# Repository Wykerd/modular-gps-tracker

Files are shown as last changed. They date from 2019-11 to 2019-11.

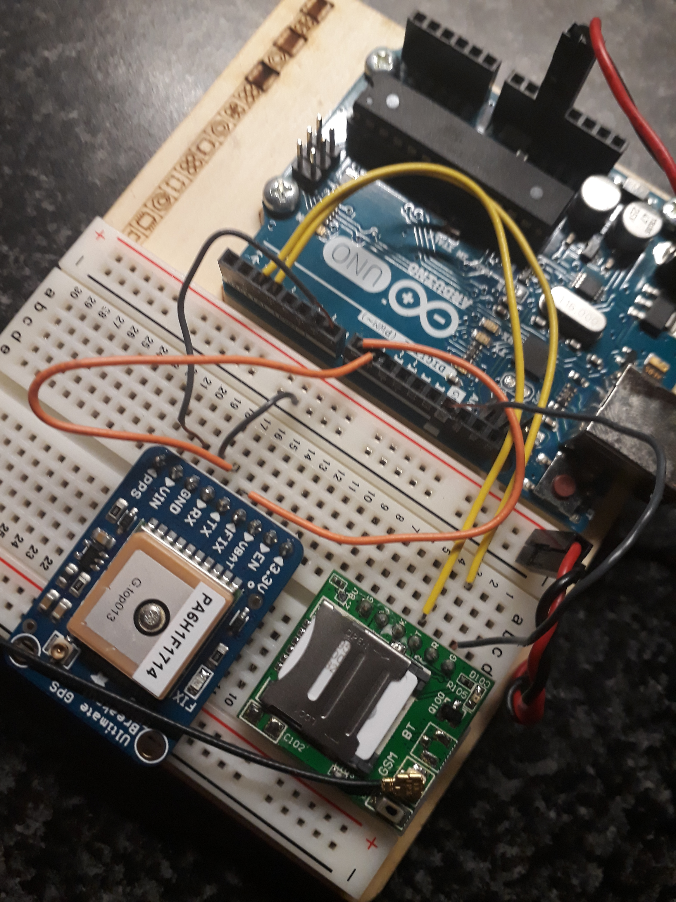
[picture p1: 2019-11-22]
Images/Hardware/20180210_222112.jpg

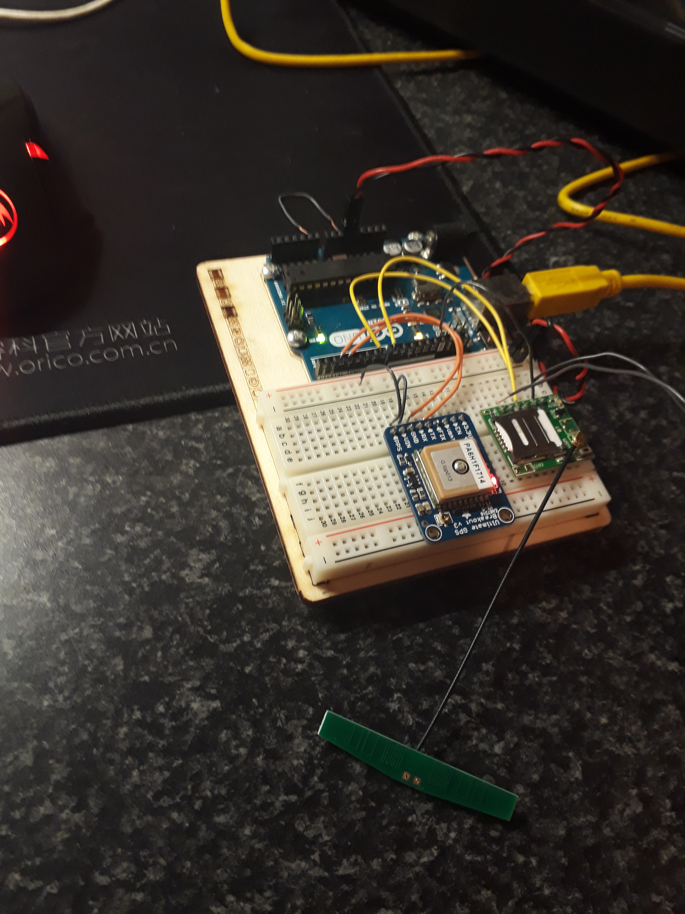
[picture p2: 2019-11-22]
Images/Hardware/20180122_201226.jpg

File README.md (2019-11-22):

# Modular GPS Tracker

This is a project made by me in 2018 when I was 16.

This project entered into the Eskom Expo Sciencefair.

Excuse the messy file structures and odd files. I had no idea of git at the time of making the project and this was a big learning experience for me.

The project is fully documented in ``Report File.docx`` Word document. An pdf converted version (which may be outdated) can be found as ``Report File*.pdf``

I might return to this project in the future but using a diffirent repo. If so, I will archive this project.

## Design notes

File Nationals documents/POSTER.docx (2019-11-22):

INTRODUCTION

Governmental Statistics show that there are high levels of theft in South Africa. Therefore, there is a need for a way to retrieve stolen goods like vehicles as well as personal property.

Although there are already GPS Tracking devices on the market, most of them are expensive and can only be used for one purpose.

ENGINEERING GOAL

The goal of this project is to design and manufacture a modular GPS tracking device that can accurately track stolen objects from anywhere in the country. The device will be modular allowing the user to add additional functionality to the core tracking module. The device should be mass producible and use pre-existing communication infrastructure to locate the device. There should be no third party involved in locating the device.

In addition to this, a secondary datalogging module will also be created to demonstrate the modularity of the core GPS Tracking device. This module should store location data like routes travelled on an SD Card in a common file format

PROCEDURES FOR CORE MODULE

First, the components that were required to design the core device was chosen. The three main components used in the device is a microcontroller that interfaces with and controls all the chips, a GPS module, and GSM module (used to send and receive SMSs)

The schematic and PCB layout was designed in a free CAD software called EasyEDA. The PCB layout was sent to a factory to be fabricated.

After the components were purchased and the PCBs arrived from the factory, the board was assembled.

Software had to be made for the microcontroller so that the device would function properly. The software was created in the Arduino IDE and was programmed in C.

Two cases were designed and printed to house the PCB and make the device more modular. It is designed to make it easier for the other modules to attach to the core module.

Lastly, the device was tested against the design criteria to determine how well it performed.

PROCEDURES FOR DATALOGGING MODULE

As with the core module, the components required had to be chosen first. The main components used in the datalogger is a microcontroller that controls writing to the SD Card, an USB-to-TTL UART Converter that makes it possible to update the software of the core module via the onboard USB port. The power from the USB port is used by the charge management IC to charge a 18650 Lithium-Ion battery.

The schematic and PCB layouts were created next and the PCB layout was sent to a factory to be fabricated.

After the components and PCBs arrived from the factory, the boards were assembled.

A New version of software had to be written for the core module for it to be able to communicate with the microcontroller of the datalogger, which code was also written for so that it can communicate and write data to the SD Card.

Lastly, the secondary datalogging module was tested with the core module against the design criteria to determine how well it performed.

RESULTS

P R O D U C T I O N

Both the core and secondary datalogging devices are contained on single multi-layered PCBs thus these devices can easily be manufactured as PCB fabrication is a very fast and cheap process.

Neither the core or datalogging module uses off the shelf components resulting in a steep drop in the price per unit.

All the components on both the core and datalogger are surface mount components, these types of components are the most common type components used in factories, it can easily be assembled by pick and place machines minimizing the need for human involvement in production (which further decreases production cost).

C O R E M O D U L E

The core device uses SMS to communicate with the user. Thus, it does not require a subscription to a third party.

The core device is modular. The code of the device can be changed and there are 3 programmable pins available for use by other modules added later.

RESULTS

D A T A L O G G I N G M O D U L E

The secondary datalogging module is capable of logging location data in a common file format called GPX. It is the standard format for logging location data and can be used by fitness apps and software map apps.

The device is lightweight weighing only 22 grams without the battery and 68 grams with the battery.

C O M P A R I S O N T O E X I S T I N G T R A C K E R S

Criterion | Common GPS Tracker | Modular GPS GSM Tracker
Upgradability | Most GPS trackers on the market have a closed ecosystem and are closed source. Software cannot be upgraded and there is no way to add additional hardware to the device. It is impossible to add additional functionality to these trackers | This tracker’s software is open source and can easily be upgraded via a computer. The tracker’s hardware has 3 I/O pins that can be programmed. Third-party developers can create their own hardware and software that adds additional functions to the device
Applications | Can be used to track a lot of items including people and vehicles, but other uses are limited. | Can be used to track a lot of items but can also be used for other applications like detecting odd movement of farm animals, notifying the user when the tracker exits a certain region etc.

APPLICATIONS

Since the core device is modular, it can be used for a variety of applications.

It can be used as a standalone in a vehicle, put inside a wallet or bag or it can be given to a child to monitor his/her whereabouts.

The device works the best outdoors, which narrows the uses of the device if a highly accurate location is required.

The core device can be used with the datalogging module by shipping companies to track the route that a shipment followed. It can be used by truck companies to track where their drivers drove during their shifts, or simply to record/log a workout or vehicle trip.

POSSIBLE EXTENSIONS

Improvements can be made to extend the device’s battery life.

More software can be created to make the user experience better or allow for additional functionality without more hardware and even more modules could be created to add functionality.

The GSM antenna can be put onto the PCB making the assembly process easier.

DISCUSSION

Each prototype of both modules got smaller because as prototypes were developed, the components used for testing the device became unnecessary and were removed leading to a smaller form factor. This also lead to a decrease in current draw.

The core device has several limitations: The device can only get a GPS fix if it is outside unless it is placed near a window. The device will function indoors if an initial GPS fix was gained outside.

The limitations of the datalogging module is that it can only write data to the SD Card, the core module cannot read any data from the SD Card. This issue can be minimized by rewriting the code of the MCU of the datalogger to allow reading from the SD Card as well.

CONCLUSION

According to all the results obtained in this project, the Modular SMS GPS Module designed and manufactured meets the requirements and criteria needed to accomplish the engineering goal. It is modular, uses a low current, is cheap to manufacture and requires no subscription to a third-party company.

The datalogging module designed and manufactured also meets the requirements needed to accomplish the engineering goal. It logs to an SD Card in a common file format and works seamlessly with the core module.

Therefore, in conclusion, the project has achieved its goal.

ACKNOWLEDGEMENTS

- Thanks Rochelle and Malan Wykerd for funding the research of core module and everyone who sponsored money for the datalogging module’s research.
- Thanks Johann Erasmus for soldering the first attempt at assembling the final prototype, helping with the debugging of the final prototype of the core module’s first attempt, and soldering one of the datalogging modules.
- Thanks Dr. Danie Ludick (PhD) for organizing with the University of Stellenbosch to populate the final prototype of the core module and datalogging module, reading through my designs and helping to debug the first attempt to assemble the final prototype of the core.
- Thanks to Grant Parkes for giving advice regarding the case design and for arranging the manufacturing of the case.
- Unpopulated PCBs fabricated by JLCPCB.
- ALL IMAGES ON THIS POSTER IS TAKEN BY DANIEL WYKERD
- Poster background watermark retrieved from https://openclipart.org/detail/296685/seamless-circuit-board-pattern

BIBLIOGRAPHY

1. Arduino, n.d.. ArduinoToBreadboard. [Online] Available at: https://www.arduino.cc/en/Tutorial/ArduinoToBreadboard [Accessed 13 04 2018].
2. Arduino, n.d.. Reference GSM Library. [Online] Available at: https://www.arduino.cc/en/Reference/GSM [Accessed 06 02 2018].
3. SIMCom Wireless Solutions, 2017. SIM800C Hardware Design. [Online] Available at: http://simcom.ee/documents/SIM800C/SIM800C_Hardware_Design_V1.05.pdf [Accessed 8 5 2018].
4. Adafruit Industries, 2012. Learn Adafruit Ultimate GPS Downloads. [Online] Available at: https://learn.adafruit.com/adafruit-ultimate-gps/downloads [Accessed 5 5 2018].

FULL BIBLIOGRAPHY IN REPORT FILE

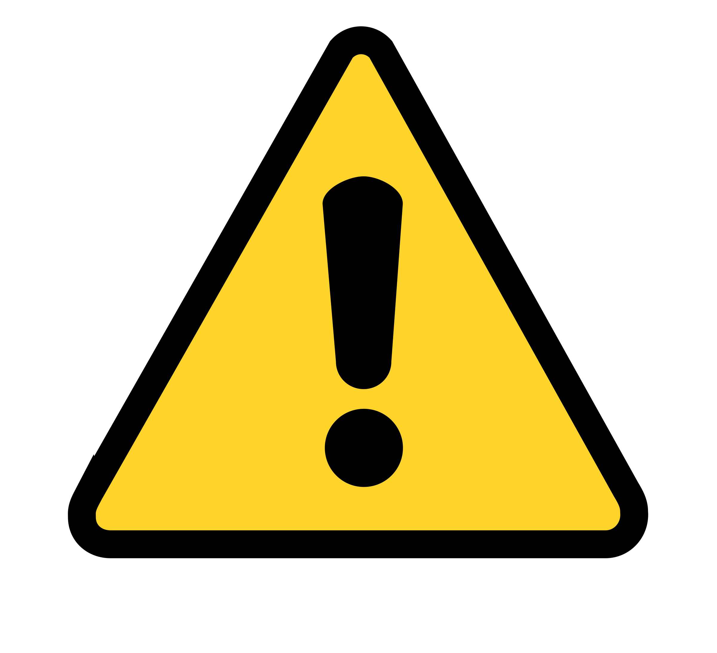
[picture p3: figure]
Image result for warning transparent
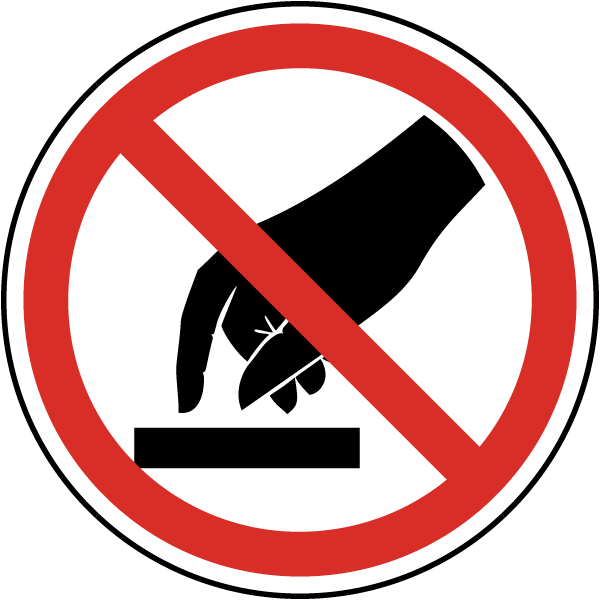
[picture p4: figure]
Image result for do not touch

DO NOT TOUCH THE ELECTRONICS!

THE ELECTRONICS ARE ELECTROSTATIC SENSITIVE

MODULAR

GPS GSM

TRACKER

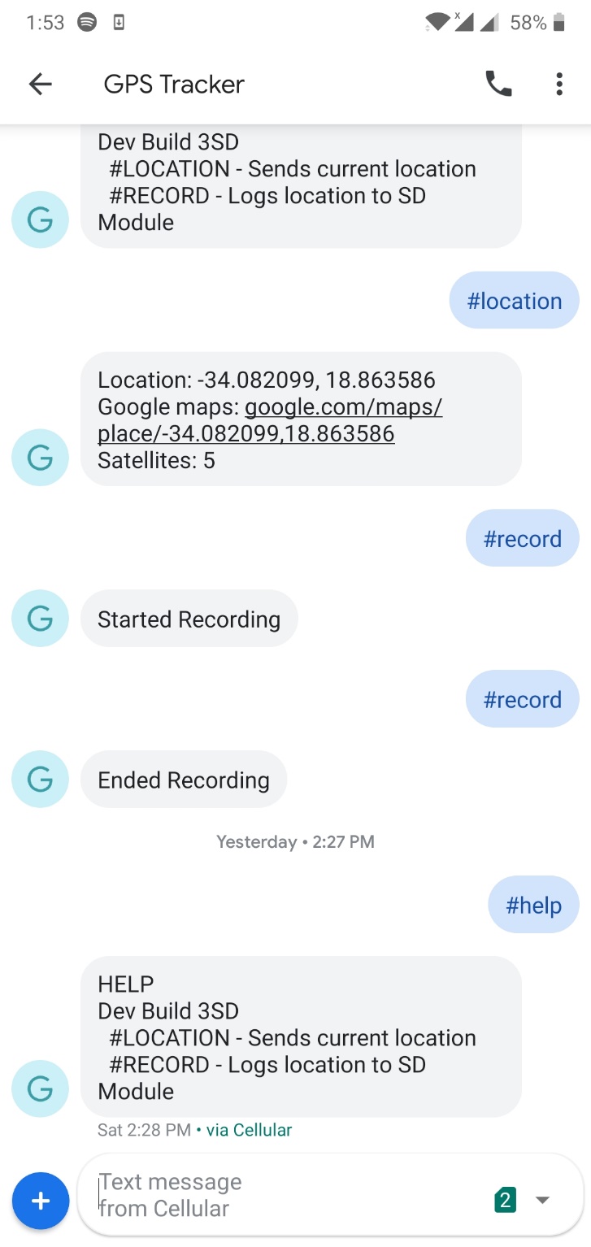
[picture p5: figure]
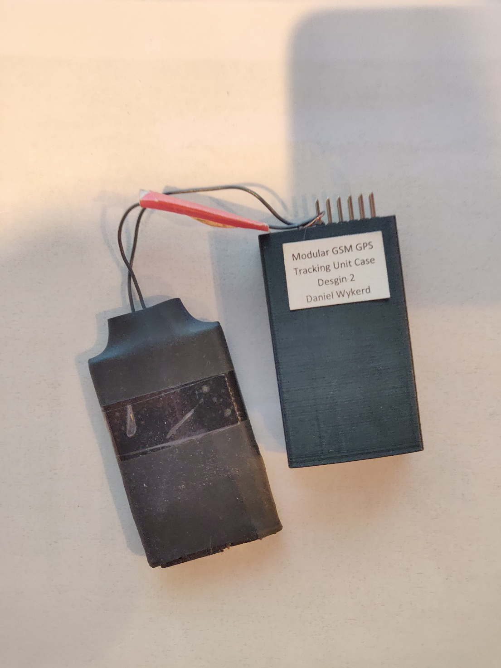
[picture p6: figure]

STANDALONE CORE MODULE SETUP

DANIEL

WYKERD

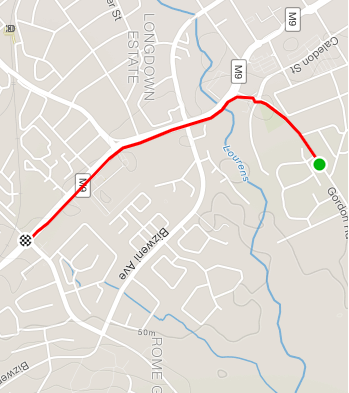
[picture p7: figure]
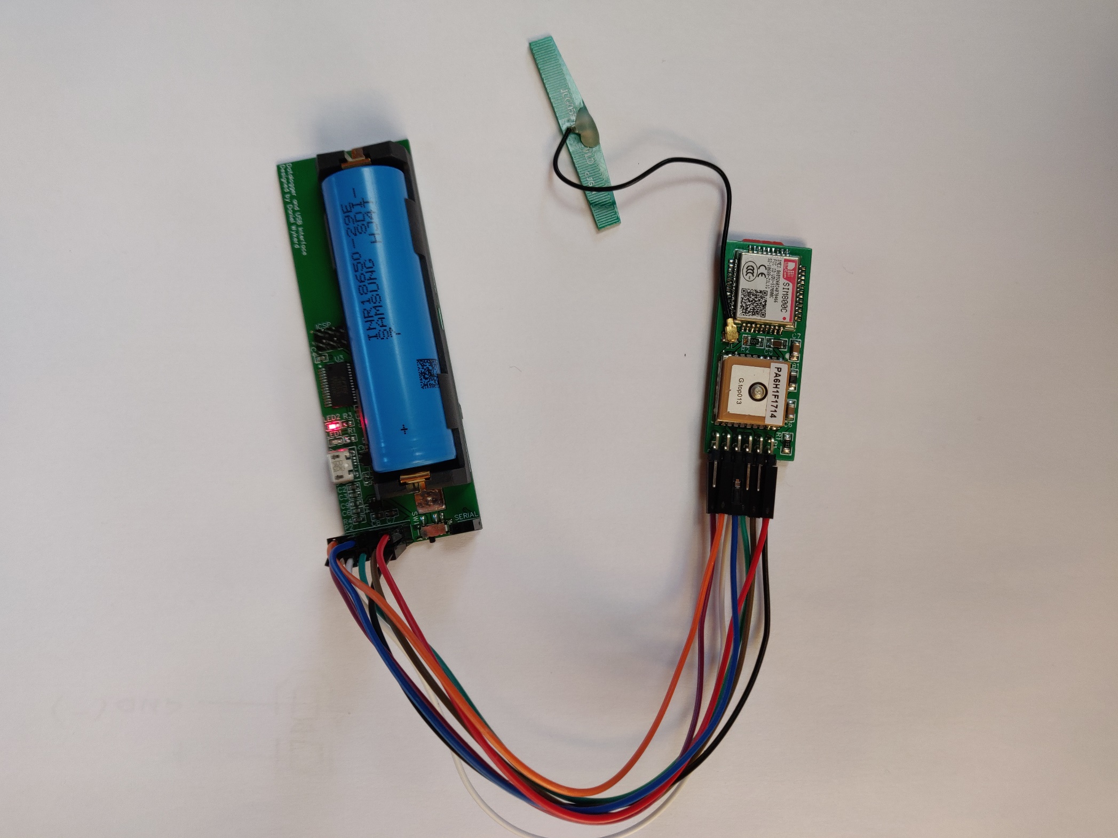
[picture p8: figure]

DATALOGGING MODULE SETUP

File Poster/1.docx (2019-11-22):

MODULAR

GSM GPS

TRACKER

INTRODUCTION

Governmental Statistics show that there are high levels of theft in South Africa. Therefore, there is a need for a way to retrieve stolen goods like vehicles as well as personal property.

Although there are already GPS Tracking devices on the market, most of them are expensive and can only be used for one purpose.

ENGINEERING GOAL

The goal of this project is to design and manufacture a modular GPS tracking device that can accurately track stolen objects from anywhere in the country. The device will be modular allowing the user to add additional functionality to the core tracking module. The device should be mass producible and use pre-existing communication infrastructure to locate the device. There should be no third party involved in locating the device.

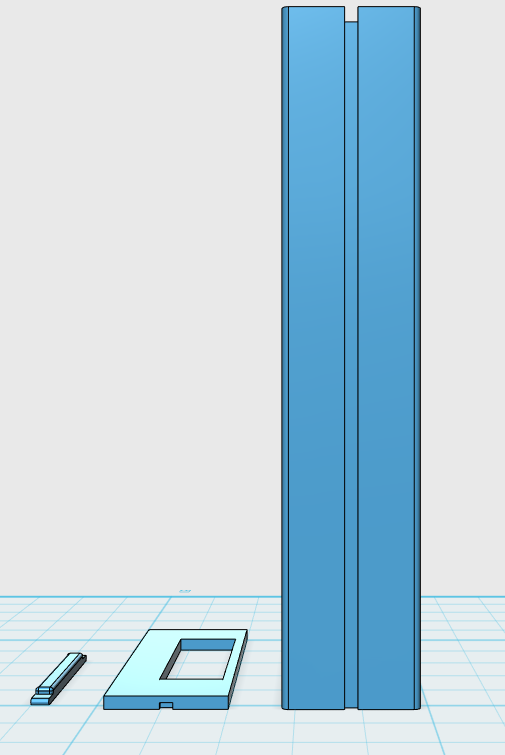
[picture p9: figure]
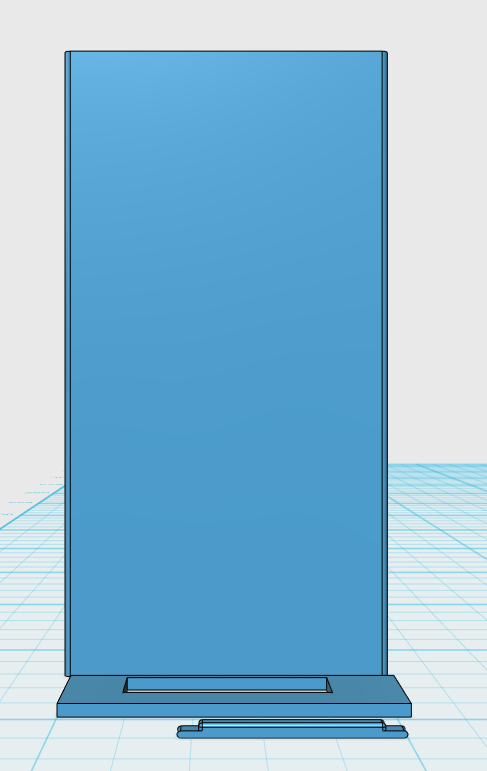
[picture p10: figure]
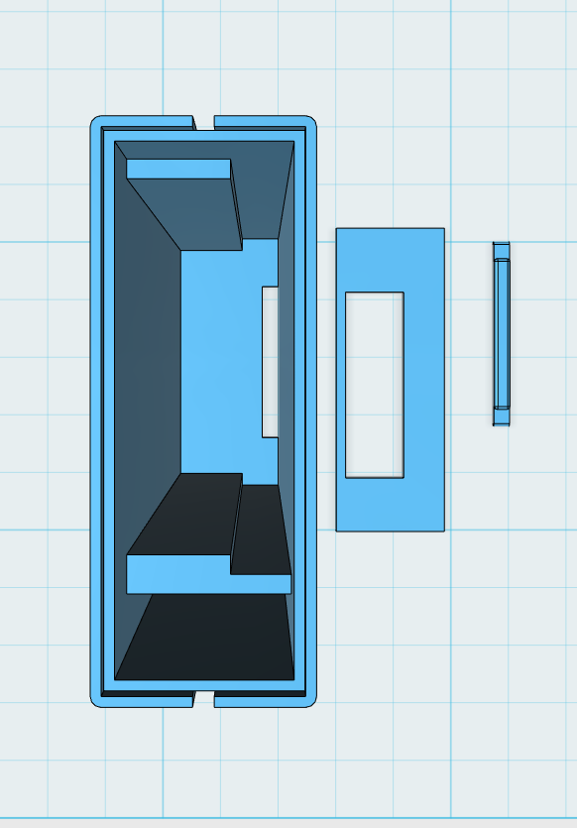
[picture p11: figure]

CASE DESIGN

THE CASE WAS DESIGNED BY DANIEL WYKERD IN 123D Design

FAILED

PROTOTYPE

SUCCESSFUL

PROTOTYPE

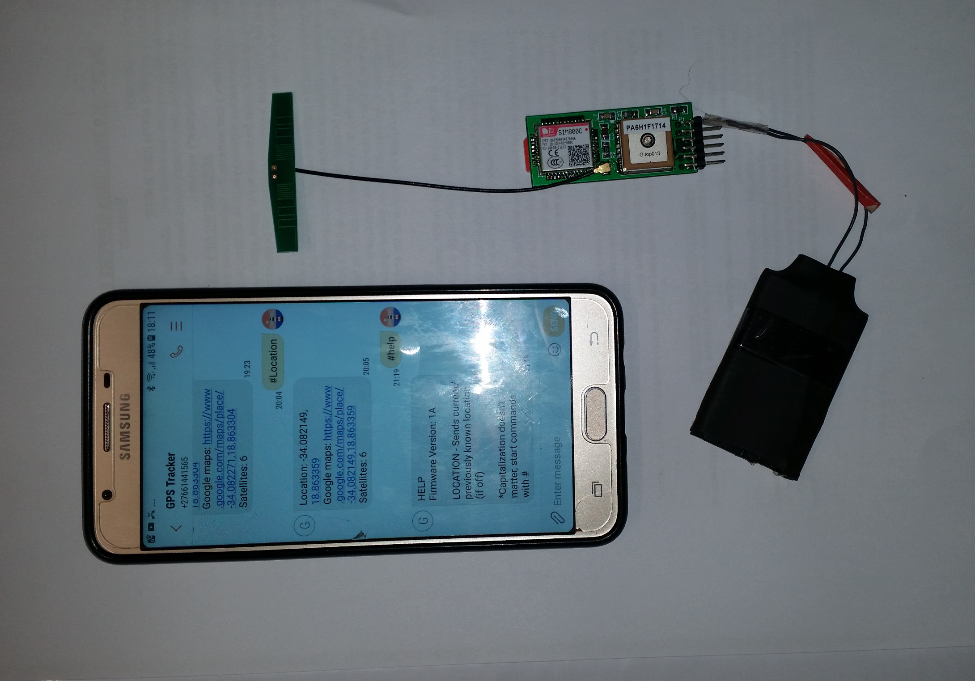
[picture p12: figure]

APPLICATIONS

Since the device is modular, it can be used for a variety of applications.

It can be used in a vehicle, put inside a wallet or bag or it can be given to a child to monitor his/her whereabouts.

The device works the best outdoors, which narrows the uses of the device if a highly accurate location is required.

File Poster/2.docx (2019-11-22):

First the components that were required to design the device was chosen. The three main components used in the device is a microcontroller that interfaces with and controls all the chips, a GPS module, and GSM module (used to send and receive SMSs)

The schematic and PCB layout were designed in a free CAD software called EasyEDA. The PCB layout was sent to a factory to be fabricated.

After the components were purchased and the PCBs arrived from the factory, the board was assembled.

Software had to be made for the microcontroller so that the device would function properly. The software was created in the Arduino IDE and was programmed in C.

A case was also designed for the device, but it was never manufactured due to time constraints and the high cost of small scale 3d printing.

Lastly, the device was tested against the design criteria to determine how well it performed.

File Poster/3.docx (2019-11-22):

The device meets all the requirements to succeed in the engineering goal.

The device is contained on a single multi-layered PCB thus the device can be easily manufactured as PCB fabrication is a very fast and cheap process.

There is no off the shelf components used in the device resulting in a steep drop in the price per unit.

All the components are surface mount components these types of components are the most common type components used in factories, it can easily be assembled by pick and place machines minimizing the need for human involvement in production (which further decreases production cost).

The device uses SMS to communicate with the user. Thus, it does not require a subscription to a third party.

The device is modular. The code of the device can be changed and there are 3 programmable pins available for use by other modules added later.

The case can easily be slid into other modules using the grooves on the sides of the case.

The device has a battery life of over 48 hours on a 2350 mAh according to tests done.

The device costs only R293.47 to manufacture.

RESULTS AND ANALYSIS

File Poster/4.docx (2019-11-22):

Discussion

Each prototype got smaller because as prototypes were developed, the components used for testing the device became unnecessary and were removed leading to a smaller form factor. This also lead to a decrease in current draw.

The device has several limitations: The device can only get a GPS fix if it is outside unless it is placed near a window. The device will function indoors if an initial GPS fix was gained outside.

POSSIBLE EXTENSIONS

Improvements can also be made to extend the device’s battery life.

Another version of the software could be created that constantly streams the device’s location to a website, allowing the user to view a log of where the device was.

The GSM antenna can be put onto the PCB making the assembly process easier.

CONCLUSION

According to all the results obtained in this project, the Modular SMS GPS Module designed and manufactured in this project meets the requirements and criteria needed to accomplish the engineering goal exceptionally well. It is modular, uses a low current, is cheap to manufacture and requires no subscription to a third-party company.

Therefore, in conclusion, the project has achieved its goal.

Acknowledgments

- Rochelle and Malan Wykerd for funding this project.
- Johann Erasmus for soldering the first attempt at assembling the final prototype and helping with the debugging of the final prototype’s first attempt.
- Dr. Danie Ludick for organizing with the University of Stellenbosch to populate the final prototype, reading through my designs and helping to debug the first attempt to assemble the first prototype.
- Unpopulated PCBs fabricated by JLCPCB.

BIBLIOGRAPHY

1. Arduino, n.d.. ArduinoToBreadboard. [Online] Available at: https://www.arduino.cc/en/Tutorial/ArduinoToBreadboard [Accessed 13 04 2018].
2. Arduino, n.d.. Reference GSM Library. [Online] Available at: https://www.arduino.cc/en/Reference/GSM [Accessed 06 02 2018].
3. SIMCom Wireless Solutions, 2017. SIM800C Hardware Design. [Online] Available at: http://simcom.ee/documents/SIM800C/SIM800C_Hardware_Design_V1.05.pdf [Accessed 8 5 2018].
4. Adafruit Industries, 2012. Learn Adafruit Ultimate GPS Downloads. [Online] Available at: https://learn.adafruit.com/adafruit-ultimate-gps/downloads [Accessed 5 5 2018].

FULL BIBLIOGRAPHY IN REPORT FILE

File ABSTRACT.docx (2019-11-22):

ABSTRACT

Compiled by Daniel Wykerd (10A3)

Title:

Modular GSM GPS Tracking Device

Project Type: Engineering

Category: Electronic and Electrical Engineering

Due to the high rate of vehicle and petty theft as reported by last year’s governmental crime statistics and high prices of existing GPS trackers on the market, the decision was made to design, test and manufacture a modular GSM GPS tracking unit that can be used for multiple applications.

The unit had to comply to the following criteria to meet its goal: it had to be modular, easily manufacturable, compact, draw low current and it should not need a subscription to a third party. Enthesis was placed on reducing the possible retail cost below the prices of currently available alternatives.

Research was done on the parts and skills required to design a schematic and PCB layout accordingly. Software was developed to compliment the hardware. Two prototypes preceded the final design to test the concept and improve on the design criteria. After the final prototype was designed, the final PCB layout was then sent to a factory to be fabricated. The final step was to assemble and test the board to see how well it met the criteria.

The final design proved to be very effective and accurate in its GPS tracking capabilities. All criteria were met and some even exceeded beyond expectation.

Abstract for Modular GSM GPS Tracking Device; By Daniel Wykerd 2018

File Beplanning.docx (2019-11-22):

Daniel Wykerd (Individual) Teacher: Ms. Blomerus

Class: 10A3 7 FEB 2018

Type of project: Engineering Project

Category: Electrical and Electronic Engineering

Engineering Goal

The goal of this project is to ultimately design, test, produce and manufacture an electronic device that can accurately track a bicycle from anywhere in the country. The reason for designing this device is to prevent bicycle theft by allowing the bike owner to view where their bike is located at all times. The tracker should be mounted to a bicycle and stay hidden from thieves. The device will have to last quite a long time without recharging and will thus have to draw minimal current to prolong battery life. The device/circuity should be as small as possible, preferably smaller than a AA-battery in length. There should be no third-party involved in receiving the co-ordinates, the end user should be able to retrieve the location themselves. This device should be designed in such a way that it can easily be manufactured.

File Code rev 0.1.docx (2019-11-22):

First working code

#include <GSM.h>

// PIN Number for the SIM

#define PINNUMBER ""

GSM gsmAccess;

GSM_SMS sms;

char senderNumber[20];

#include <AltSoftSerial.h>

#include <TinyGPS++.h>

#define GPSBaud 9600

AltSoftSerial ss;

TinyGPSPlus gps;

void setup() {

// initialize serial communications and wait for port to open:

Serial.begin(115200);

ss.begin(GPSBaud);

while (!Serial) {

; // wait for serial port to connect. Needed for native USB port only / debugging

}

Serial.println("Bike Tracker Booting...");

// connection state

boolean notConnected = true;

// Start GSM connection

while (notConnected) {

if (gsmAccess.begin(PINNUMBER) == GSM_READY) {

notConnected = false;

} else {

Serial.println("Not connected");

delay(1000);

}

}

Serial.println("GSM initialized");

Serial.println("Waiting for messages");

}

void loop() {

char c;

//Parses the NMEA sentences (GPS data)

getGPS();

// If there are any SMSs available()

if (sms.available()) {

Serial.println("Message received from:");

// Get remote number

sms.remoteNumber(senderNumber, 20);

Serial.println(senderNumber);

//Reacts to the messages

while (c = sms.read()) {

String msg = String(c);

msg.toUpperCase();

Serial.print(msg);

if(msg.indexOf('LOCATION') >= 0){

sendGPS();

}

else if(msg.indexOf('HELP') >= 0){

sms.beginSMS(senderNumber);

sms.print("HELP PAGE");

sms.print("\nLocation - sends location");

sms.print("\nStatus - sends bunch of info for advanced users");

sms.print("\nOFF - puts device in lo power mode");

sms.print("\nON - device only reactivates if this command is sent after turnt off");

sms.print("\n*Commands are not case sensitive");

sms.endSMS();

}

}

Serial.println("\nEND OF MESSAGE");

// Delete message from modem memory

sms.flush();

Serial.println("MESSAGE DELETED");

}

delay(1000);

}

void getGPS(){

while (ss.available() > 0)

gps.encode(ss.read());

}

void sendGPS(){

sms.beginSMS(senderNumber);

sms.print("Location: ");

sms.print(gps.location.lat(), 6);

sms.print(", ");

sms.print(gps.location.lng(), 6);

sms.endSMS();

}

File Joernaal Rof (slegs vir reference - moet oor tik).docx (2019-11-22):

1 Get idea

2 Research on for to achieve goal

3 Research about components

4 Research about components

5 Research about components and circuit

6 Start creating circuit diagram

7 Creating further circuit diagrams

8 Research about where to purchase

9 Additional research about where to purchase

10 Obtain quote from Communica

- Wait
- Wait
- Wait

14 Obtain Quote

20ste – Receive parts from Communica. Test GPS – Success!

Test GSM – Boot running… Suspect insufficient power, recommended is 4v

21ste – Looking for buck converter online as well as multimeter

23ste – Make lipo battery as power source from old cellphone battery in order to eliminate buck converter

Test GSM – success

28ste – get idea to move to modular design which will pen GPS to be used for other aplications

30ste – Start paper work

Write engineering goals and categories on paper

Beginning research from sources gathered

6/02:

Write code to reply on certain SMS messages

Did to much testing ran out of airtime on simcard!

Created code to respond to specific sms’s like ‘help’ and ‘location’

----- explain--------

7/2

Tried adding GPS info to code. Ended up with error. Adafruit gps and Gsm both use same library causing errors (software serial) while compiling. Switched to TinyGPS++ still got errors. Finally found out That I needed AltSoftSerial as I can’t use 2 instances of software serial.

After much trial and error I have gotten the device to output the location

10/02

Revised the code to send a link to google maps if the command ‘location’ is sent to the device:

void sendGPS(){

sms.beginSMS(senderNumber);

sms.print("Location: "); //Sends location

sms.print(gps.location.lat(), 6);

sms.print(", ");

sms.print(gps.location.lng(), 6);

sms.print("\nGoogle maps: "); //Sends link to Google Maps

sms.print("https://www.google.com/maps/place/");

sms.print(gps.location.lat(), 6);

sms.print(",");

sms.print(gps.location.lng(), 6);

sms.print("/");

sms.endSMS();

}

Wrote the status and OFF commands’ code but the first try failed, I modified the code and it should work but the first try of the code spammed a bunch of messages and used all the airtime on the simcard. I wil have to buy more tomorrow. Here is the code:

else if(msg.indexOf('STATUS') >= 0){

sendStat();

}

else if(msg.indexOf('OFF') >= 0){

gpsPower = False;

digitalWrite(gpsVIN, LOW);

sms.beginSMS(senderNumber);

sms.print("GPS is now off!");

sms.endSMS();

}

And:

void sendStat(){

sms.beginSMS(senderNumber);

sms.print("Bike Tracker Status: ");

if(gpsPower){

sms.print("ON");

sms.print("\nSatellites: ");

sms.print(gps.satellites.value());

}else{

sms.print("OFF, send command 'on' to reboot the gps");

}

sms.endSMS();

}

03/03

Brought new airtime and tested the code written on 10th Feb. It did not work as the microcontroller ran out of space for variables. I shortened all the sentences to preserve space, but the code would not work as expected and continuously sent SMS’s. I thus decided to rewrite the SMS commands, removing the status and adding the amount of satellites in the location SMS. I reprogramed the ON/OFF feature of the GPS and made it so that when of is send the GPS is turned off and when on is sent it turns back on. Unfortunately, this lead to stability issues as the microcontroller once again ran out of space. This forced me to reprogram this function again. Sending off still revokes power from the GPS but sending location will return power to the GPS module. This code turned out great as sending location after the GPS was switched off would send the previously know location and will update the data once it has acquired 3 or more satellites. The complete updated code on the next page.

I also worked on the case for the final PCB. By making adjustments to the design. This idea sketches are also on the next pages.

05/03

Made final tweaks and simplifications to the software and think that it is about time to make a new hardware prototype that gets rid of the Arduino and opts for a atmega 328P-PU without an external clock to preserve power and make the device ready for testing and designing the third and final prototype, the self-contained PCB.

Also need to purchase more airtime as while testing I ran out of it. Do not think that running out of airtime will be a problem in the final build as users will not query the device several dozen times a day.

08/03

Tried testing the GPS inside a car but ran into errors in the software after the device was sent an advert by Vodacom. I noticed that this would be a possible problem in a real-world scenario, so I reprogrammed the device to only respond to SMSs starting with an ‘#’ symbol. Now the device can determine which SMSs are commands and which are not and only reply to ones that are commands. This is hopefully the last alterations for this prototype. Next, I will start working on the next prototype. For this I will need a new apparatus: a multi-meter, to measure the amount of amp draw. This apparatus is needed to determine the current draw of the device, so that I can calculate how long the battery will last. The goal of the next prototype as stated in a previous entry is to minimize the power consumption of the device and get rid of the Arduino in favor of an ATMEGA 328P-PU IC.

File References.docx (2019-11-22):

References:

http://mt-system.ru/sites/default/files/documents/sim5360_hardware_design_v1.06.pdf

https://cdn-learn.adafruit.com/assets/assets/000/036/282/original/flora_schem.png?1476128668

http://wiki.seeedstudio.com/images/c/c4/SIM800L_Schematic.pdf

http://wiki.seeedstudio.com/images/4/46/SIM800L_Hardware_Design_V1.00.pdf

https://cdn-shop.adafruit.com/datasheets/GlobalTop-FGPMMOPA6H-Datasheet-V0A.pdf

https://cdn-shop.adafruit.com/product-files/1946/SIM800HL-TE_Schematic+and+PCB_Reference+Design_V1.00+(1).pdf

http://www.communica.co.za/Content/Catalog/Documents/D2513229327.pdf

http://mt-system.ru/sites/default/files/documents/sim5360_hardware_design_v1.06.pdf

https://www.arduino.cc/en/Tutorial/ArduinoToBreadboard

IMAGES

https://forums.parallax.com/discussion/download/63590/SMT_sizes.jpg

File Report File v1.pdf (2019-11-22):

Modular GSM/GSRM GPS Tracking Unit

## MODULAR GSM GPS TRACKING UNIT

### ESKOM EXPO REPORT FILE

### DANIEL WYKERD

10A3

10 MEI 2018

Contents

The GSM Module | 26
The GPS Module | 27
The MCU | 29
4. Bill of Components (BOM) | 30
5. PCB Layout | 30
6. System Diagram | 32
7. Case design | 32
8. Assembly | 34
9. Software | 36
10. Analysis of results | 36
Requirements | 36
Criteria | 37
Discussion | 37
Conclusion | 38
Bibliography | 39
Acknowledgments | 40
Appendix A | 41
Appendix B | 42
Appendix C | 43
Appendix D | 44

Figure Index
Figure 1 Image of the main components (Wykerd, 2018) | 9
Figure 2 Picture of Ultimate GPS Wiring for testing (Adafruit Industries, 2012) | 10
Figure 3 Wiring of the SIM800L module to communicate with the computer (Wykerd, 2018) | 10
Figure 4 Schematic of first prototype (Wykerd, 2018) | 11
Figure 5 Breadboard layout of first prototype (Wykerd, 2018) | 11
Figure 6 Image of breadboard assembly (Wykerd, 2018) | 12
Figure 7 Example of the serial output (Wykerd, 2018) | 14
Figure 8 Example of #Location SMS (Wykerd, 2018) | 15
Figure 9 System Diagram of first prototype (Wykerd, 2018) | 15
Figure 10 Arduino as ISP (Arduino, n.d.) | 19
Figure 11 Atmega328p and 168 Arduino Pin Mapping (Arduino, n.d.) | 20
Figure 12 Schematic of second prototype (Wykerd, 2018) | 21
Figure 13 Breadboard layout of second prototype (Wykerd, 2018) | 21
Figure 14 Final assembly of second prototype (Wykerd, 2018) | 22
Figure 15 System diagram of second prototype (Wykerd, 2018) | 23
Figure 16 GSM Section of Schematic | 27
Figure 17 GPS Section of Schematic | 28
Figure 18 MCU Section of schematic | 29

Figure 19 Top Layer of PCB | 30
Figure 20 Bottom Layer PCB Layout | 31
Figure 21 PCB Layout | 31
Figure 22 System Diagram of final prototype | 32
Figure 23 Top view of case | 32
Figure 24 Right view of case | 33
Figure 25 Front view of case | 33
Figure 26 Dimensions of Top view of case | 33
Figure 27 Faulty board | 34
Figure 28 Bottom of Assembled PCB | 35
Figure 29 Top of Assembled PCB | 35
Figure 30 Programming Station | 35
Table Index
Table 1 List of possible components: | 8
Table 2 Analysis of first prototype to design criteria: | 16
Table 3 Analysis of second prototype to design criteria | 24
Table 4 BOM of third prototype | 30
Table 5 Total cost of project | 41

Introduction / Problem:
A need was identified in our country for a way to retrieve stolen goods especially vehicles like cars, motorcycles, and bicycles as well as personal property.
This project will attempt to solve this problem by designing and manufacturing a modular GPS module.
The need for this device is substantiated by multiple local governmental statistical releases. In a recent document published by the South African Police Service(SAPS) it is revealed there are 53 307 cases of car and motorcycle theft and 16 717 cases of car hijacking between April 2016 and March 2017 (South African Police Service, n.d.). It is also revealed in a statistical release done by Stats SA that there were 21 051 cases of bicycle theft, 284 252 cases of money/purse/wallet theft, and 18 119 cases of bag theft in this period. (Stats SA, 2017).
During the literature study to motivate the project several pre-existing products that prevent some of these problems by using GPS Tracking or alarm systems were identified, but most of these products are dedicated devices designed to only prevent the theft of one of the above-listed items. Research done on these devices can be found in the journal of this project. This project will attempt to design a GPS unit that can be used locate any kind of stolen goods. The device will not be limited to finding only certain objects.
There are devices like TrackingTheWorld’s ‘Enduro’ series trackers that are multipurpose (TrackTheWorld, n.d.), but most of these devices don’t offer any means to hide or attach, they are clunky, have a lot of unnecessary features, are uneconomical as they cost upwards of $289.00 and are not locally available to purchase. The device designed in this project will be customizable to suit the needs of the user and will be cheap to mass produce. The main device will have no unnecessary features and will be very small and compact. Engineering Goal:
The goal of this project is to ultimately design, test, produce and manufacture a modular electronic device that uses GPS to accurately track stolen objects from anywhere in the country. The reason for designing this device is to give users an easy way to retrieve lost or stolen goods by allowing the owner of the goods to view where their goods are located at all times. The device will be modular meaning that you can connect the core tracking module to different modules to add extra functionality and uses to the device to suit the user’s needs. The device/circuity should be as small as possible – preferably smaller than an AA-battery in length – and must be mass producible. The circuit should draw a low current as to prolong the device’s battery life. There should be no third-party involved in retrieving the coordinates thus the device should use common communication infrastructure like SMS to send the coordinates to the user.
Background Study on Required Components:
To design the tracker, background knowledge of what components will be required to create the device was required. The required components were narrowed down to a microcontroller unit(MCU), which will be used to communicate with all the other components and process their data; a GSM/GPRS module, which will receive user queries (SMSs) and respond to them; a GPS module, which will get the location of the device. This study will provide the reader with background knowledge on the integrated circuits and modules used in this project. It will also explain the reason behind choosing the components.
The Microcontroller Unit (MCU)
A Microcontroller or MCU is a small computer contained on a single integrated circuit (IC). A microcontroller contains one or more processing cores along with memory and programmable input/output peripherals (Wikipedia, 2018).
The MCU will interface with all the other core components of the device, including the GPS and GSM module. It will interpret user input from the GSM module, process the data from the GPS module and output code back to the GSM module to send the location of the device back to the user.
There are plenty of microcontrollers on the market, but the decision was made to use an Arduino as the microcontroller (MCU) for the first prototype. This decision was made because the project leader (Daniel Wykerd) already had experience using Arduino and its IDE. Another deciding factor was the fact that Arduino is open source hardware. There was also decided to make use of an Atmel MCU with an Arduino bootloader burned on it for later prototypes as their MCUs are Arduino compatible. Research was done on multiple ATMega and ATTiny MCUs (all of which are listed in my journal) but there was decided that the ATMega328p MCU was the best option as it is the same MCU used in most Arduino boards, thereby making the design and testing process much easier as this MCU is very well documented online.
The GSM/GPRS Module
The GSM Module is the part of the device that will receive the user queries and will send back the response to the user. It uses a sim card and gsm antenna to connect to pre-existing mobile providers (e.g. Vodacom).
The prime requirement for the module is to be able to send and receive SMSs. Two companies were found during the study that makes modules that meet this requirement: Quectel and SIMCom. Both these companies were well documented, but further research into local availability revealed that Quectel was not readily available in the form of development boards (boards that already have all the support circuitry), thus SIMCom modules were chosen as they were widely available for purchase on development/breakout boards. It was necessary for the modules to be on breakout boards to create the first prototype on a breadboard for testing. There was decided on 3 possible modules: SIM808, SIM800L/H, SIM800C. The SIM808 seemed like a good choice as according to its datasheet it has GPS functionality built in, but it does not have an integrated patch antenna (SIMCom, 2016). The SIM800L/H was also considered as it is readily available on breakout boards and has all the features required and more, however this chip would not be usable for the final prototype as it comes in an LGA (Land Grid Array) package which can only be reflow soldered. Thus, it was considered to use the SIM800C in the final prototype. The SIM800C has less unnecessary features and more importantly, it has an easier to solder SMT layout.
The GPS Module
According to Wikipedia.org, “The Global Positioning System (GPS), originally Navstar GPS, is a satellite-based radio navigation system owned by the United States government and operated by the United States Air Force. It is a global navigation satellite system that provides geolocation and time information to a GPS receiver anywhere on or near the Earth where there is an unobstructed line of sight to four or more GPS satellites. Obstacles such as mountains and buildings block the relatively weak GPS signals.” (Wikipedia, 2018).
There was decided on using the GlobalTop Technology Inc.’s FGPMMOPA6H GPS Module as it has an integrated patch antenna which will result in a smaller PCB footprint in the final prototype and fewer costs. The module is also used in Adafruit’s Ultimate GPS module and is well documented on their website. The module outputs its data as NMEA Sentences that can easily be read and interpreted by the MCU
Main Materials / Core Component list:
Below is a breakdown of the components that can possibly be used as well as their prices and what suppliers can be used to purchase them from:

Table 1 List of possible components:
Component | Options | Suppier | Cost
Microcontroller | Arduino UNO/PRO MINI Communica | | R 75.00
| ATMega328p-au | Mouser | $2.48
GSM/GRSM Module | SIM808 | Adafruit | $29.90
| SIM800L/H | Communica | R 236.84
| SIM800C | LCSC | $5.63
GPS Module | FGPMMOPA6H | Communica | R635.95
First Prototype:
1. Introduction and Materials Chosen
The goal of the first prototype was to test the concept of making a tracker and to ensure that all the picked components worked properly, thus the components were brought in the form of breakout boards for easy assembly.
Due to the time constraints of this project, the components for the first prototype had to be purchased locally. Thus, Communica was used as the supplier of parts for this prototype. A SIM800L breakout board and Ultimate GPS module (FGPMMOPA6H) module were purchased from them. An Arduino UNO was already purchased beforehand. A breadboard is also required for this prototype See Appendix A for the total cost of this project.

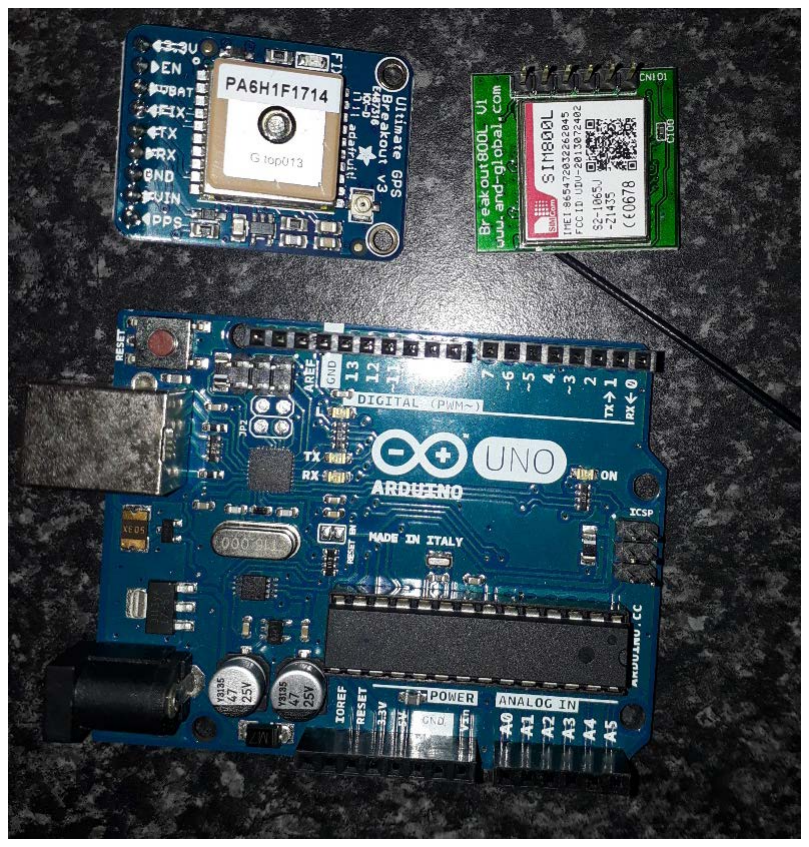
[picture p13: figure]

Figure 1 Image of the main components (Wykerd, 2018)
2. Testing the components
Before creating the first prototype the components were tested to ensure that they were in working order.
To test the GPS Module, Adafruit’s provided example code and their provided code library found on their website was used. After installing the library found on their website (Adafruit Industries, 2012), the parsing example code which can be found in the project journal on the 20th of January 2018 was used. Below is an image of the wiring:

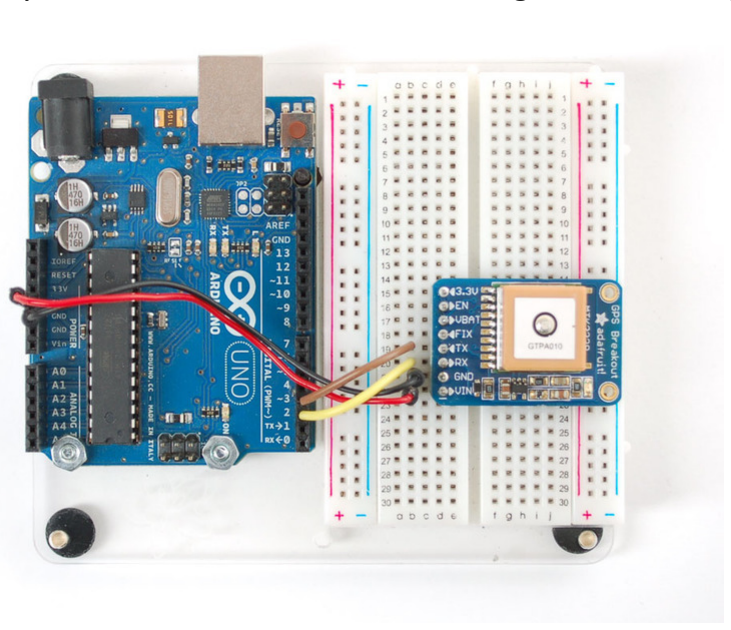
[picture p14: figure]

Figure 2 Picture of Ultimate GPS Wiring for testing (Adafruit Industries, 2012)
The test for the GPS was successful and the GPS gave accurate readings. Next, the GSM module was tested via serial. It was wired like below:

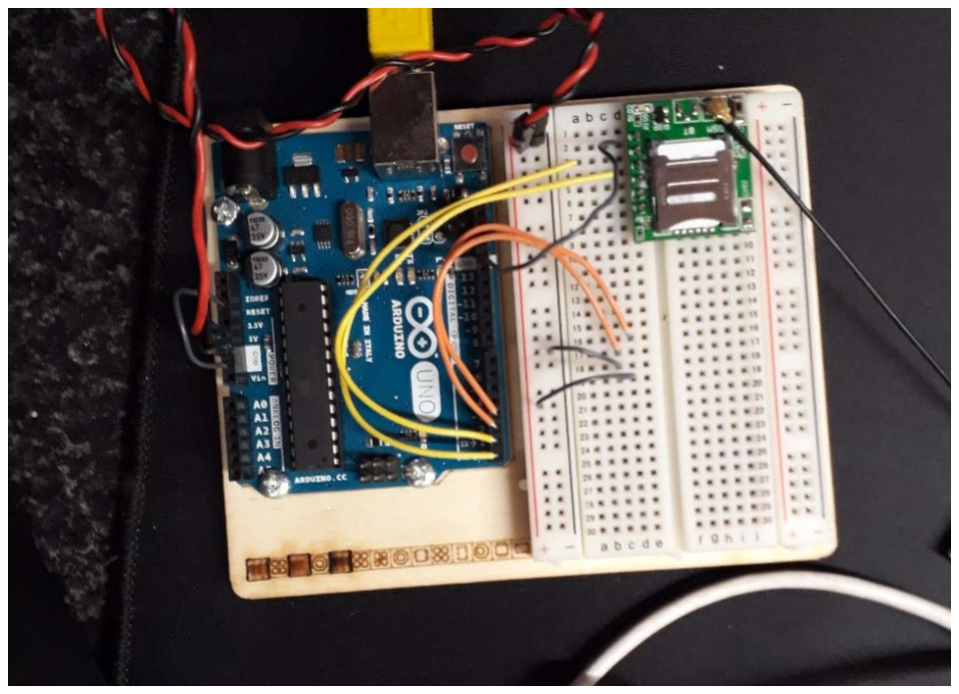
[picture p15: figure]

Figure 3 Wiring of the SIM800L module to communicate with the computer (Wykerd, 2018)
This test was also successful. However, the module could not acquire a network connection due to insufficient power. This was solved during the designing of the first prototype by adding a 3,7 V lithium-ion polymer (Li-Po) battery to power the module.

3. Schematic and Breadboard Layout:
The following two figures show the design of the first prototype and was created using Fritzing, a free open-source software that allows you to digitally make your own schematic and breadboard layout.

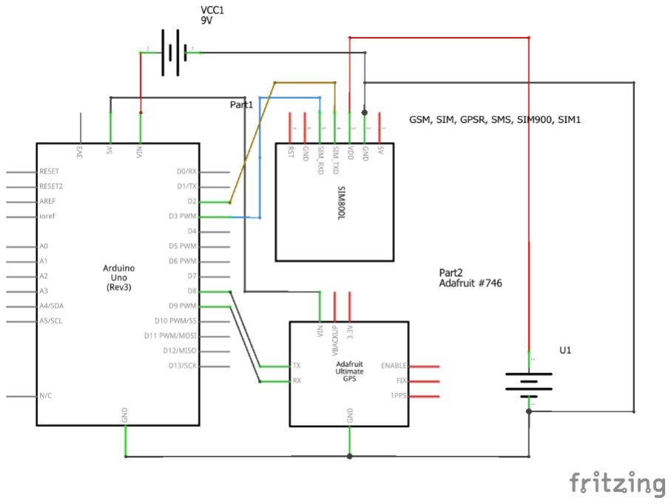
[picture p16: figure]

Figure 4 Schematic of first prototype (Wykerd, 2018)

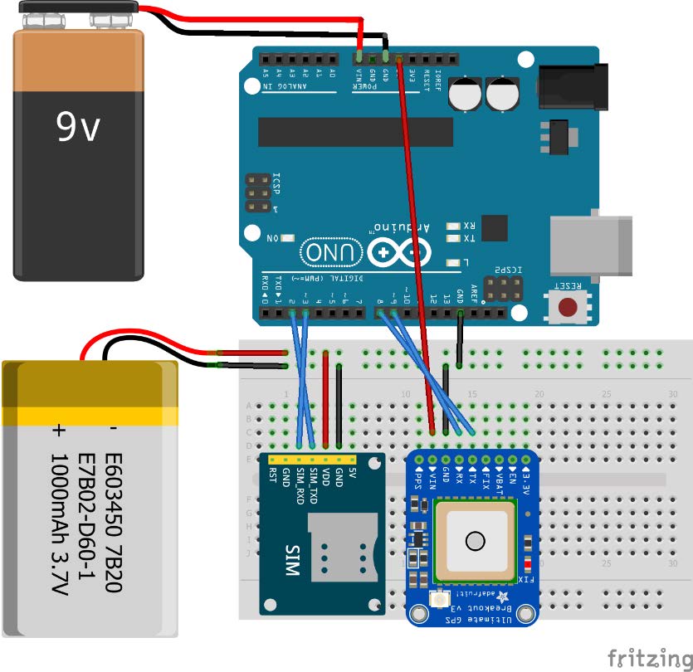
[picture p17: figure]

Figure 5 Breadboard layout of first prototype (Wykerd, 2018)
The GSM module will interface with the MCU(Arduino) by wiring the TX (Transmit) and RX (Receive) of the module and digital pin 2, which will act as the MCUs RX (going to TX of module) and 3, which has PWM (Pulse Width Modulation) to transmit commands to the module. The GPS will interface with the module by wiring the module’s RX to digital pin 9 of the MCU and the TX to digital pin 8 of the MCU. The interfacing between the modules is required as this is how all the parts will work together.
4. Assembly
The board was assembled on a breadboard using Figure 5 above as reference during the assembly. The hardware was tested beforehand in
step 2 on page 7 to decrease the chance that the prototype would fail. The final prototype is shown below in Figure 6.

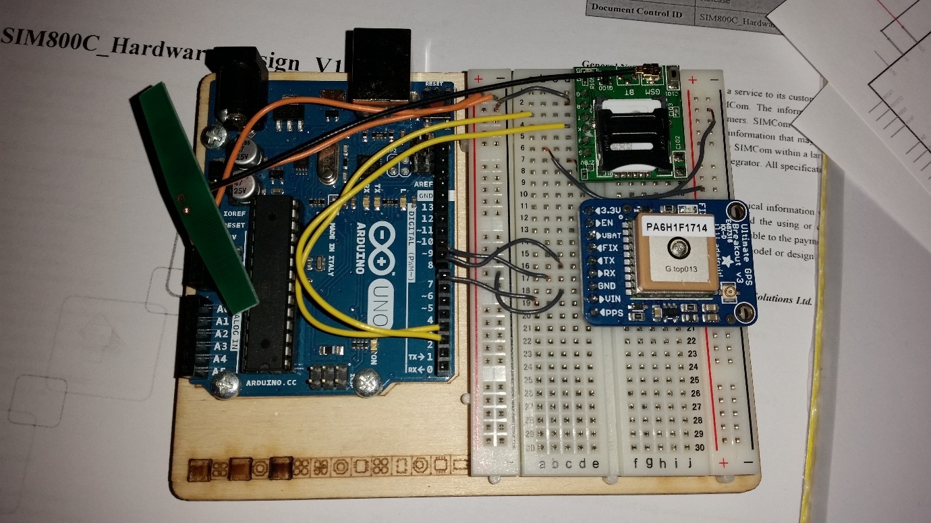
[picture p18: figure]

Figure 6 Image of breadboard assembly (Wykerd, 2018)
The wiring of the circuit was done by hand by Daniel Wykerd as was all the other assembly procedures. There was decided on using the power that the Arduino obtained via USB connection to the computer as the power source for the Arduino and GPS Module rather than a 9V-battery.
Another feature was added to the design to allow the user to turn off the GPS module. This is accomplished by connecting the GPS module’s VCC to pin 7 of the Arduino instead of directly to the Arduino’s 5V output.

5. Software
After the hardware was designed, software had to be created for the MCU so that the device will function. This software was made using the Arduino language which is a set of C/C++ functions.
Firstly, a program that can read and respond to specific SMS commands was created and tested. To communicate with the GSM, Arduino’s GSM Library (that was preinstalled on their IDE) was used and their website utilized to gain knowledge of the functions included in the library (Arduino, n.d.). At this point, the GPS was not yet implemented into the code (this code can be found in the project journal on the 6th of February 2018).
Next, it was time to implement the GPS location. To do this Adafruit GPS library was used, but this library clashed with the functions of the GSM library. Thus, an alternative was needed: TinyGPS++, this library was much more lightweight than Adafruit’s and AltSoftSerial was also used as an alternative to the IDE’s built-in SoftwareSerial library as it also clashed with the GSM library. A revision of the code was created with these libraries and can be found in the journal on the 7th of February 2018 and later the code was further adapted to the more final code available in the journal on the 10th of February 2018.
Lastly, GPS off feature was added (the code of which is available in the journal on the 10th of March). This code was the final code for this prototype. The code can be found in Appendix B.
The software also lets the Arduino output valuable debugging information through the serial port (Rx and Tx) to the computer via USB and can be viewed using a serial monitor application (like the one built into the Arduino’s IDE). The debugging output works like follows and an example can be found in figure 7 below.
Upon applying power to the module the line “Boot” is printed to the serial port to verify that the device is indeed booting up. Once the device has registered to a network the line “OK” is printed, this means the device is ready for commands. NOTE: this does not mean the device has a GPS fix. If a message is sent to the device the following lines are printed to serial: The sender’s number; the command sent, if the message does not start with a ‘#’ the word “INVALID” will be printed to serial; The word “DEL” meaning

that the device has completed the command, deleted the message from the sim card and is ready to receive the next command.

Figure 7 Example of the serial output (Wykerd, 2018)
6. Usage of The Device
In this section, an explanation is given on how the user will retrieve the location of the device.
The user will send a command to the device via SMS, there are three possible commands the user can send to the device. The command “#Location” (not case sensitive) can be sent to the number of the sim card inside the device (the device will require a sim card loaded with airtime to send the response back) to retrieve the device’s location. The format of the SMS can be seen in Figure 8 below. The first line of the SMS includes the coordinates, the second includes a link to Google Maps that shows the location of the device on Google Maps. The last line shows the number of satellites that the GPS module has acquired, this is for debugging and to show the quality of the GPS fix. If there is no GPS fix an SMS saying “Acquiring satellites” will be sent.

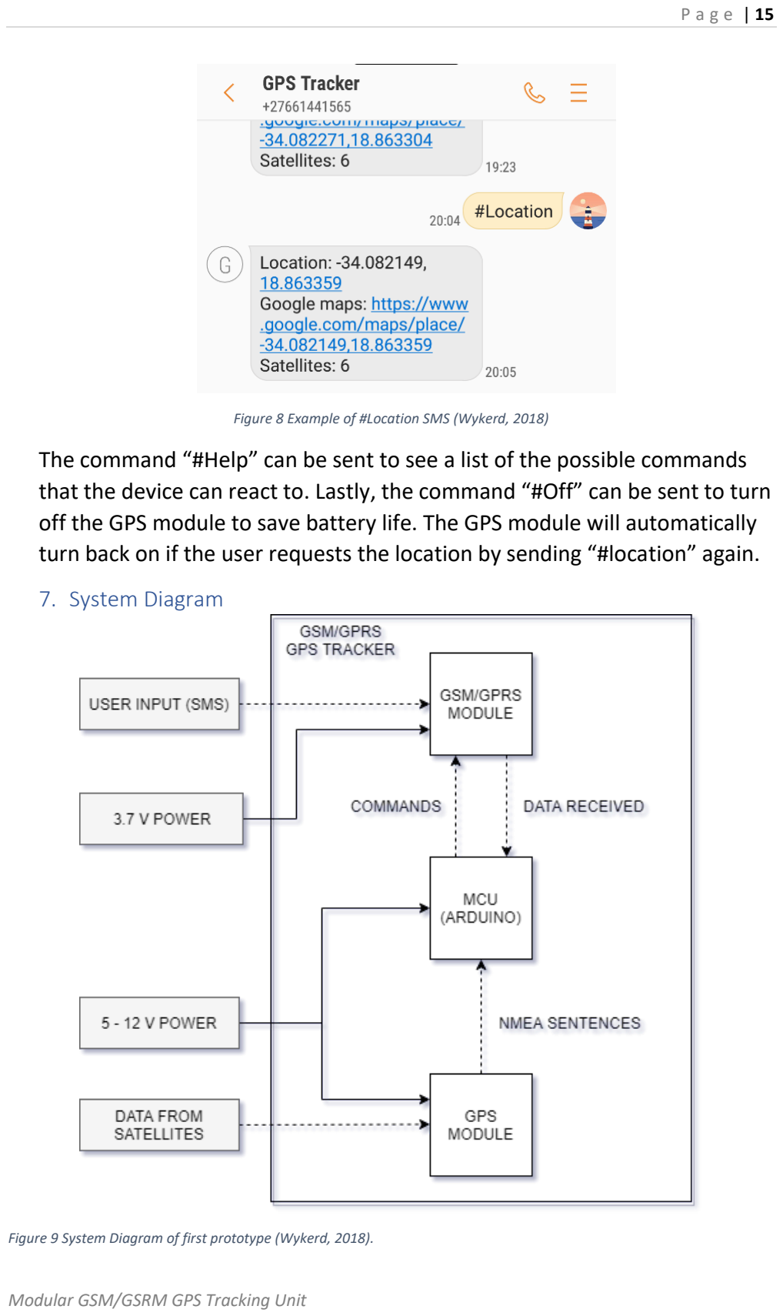
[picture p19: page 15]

Figure 8 Example of #Location SMS (Wykerd, 2018)
The command “#Help” can be sent to see a list of the possible commands that the device can react to. Lastly, the command “#Off” can be sent to turn off the GPS module to save battery life. The GPS module will automatically turn back on if the user requests the location by sending “#location” again.
7. System Diagram

Figure 9 System Diagram of first prototype (Wykerd, 2018).

8. Analysis of prototype:
The prototype was analyzed using the design requirements and criteria outlined in the research plan to determine how well the project succeeds in the engineering goal on page 3.
Requirements
Since the goal of the first prototype was to test the concept of creating a GPS Tracker and not to be reproduced, some of the requirements were not met.
The device is easily manufacturable, but only in small scale, it would be uneconomical to produce this prototype on a mass scale and the electronics of the device is not permanently attached and can easily be disassembled. This easy disassembly was necessary so that debugging can be done fast, and components can be rewired and/or replaced in a matter of seconds.

The device does not get its power from one power source, this issue is addressed in the next prototype by removing the Arduino entirely and opting for a standalone Atmel MCU.
Criteria

Table 2 Analysis of first prototype to design criteria:
Criterion | How well does the device meet the criterion? | Suggested improvements that can be made:
The device should draw a low current to prolong the battery life. | The device is powered via the USB of the computer. It does not use a battery as its primary energy source. There are measures in place to preserve power, this includes the “#Off” command that will turns of the GPS module. | This issue can be eliminated by getting rid of the Arduino and using a standalone MCU instead.
The device should have a small form factor | The device has a footprint of approx. 12cm*9.5cm*4cm. It meets the criterion very badly. | The device’s size can be cut in half by replacing the Arduino with a standalone MCU.
The device should be user-friendly. | The device’s location can be accessed via SMS. The full list of commands can be found under ‘usage of the device’ | At this moment no improvements can be made to make the device more user-friendly on the software

| on page 10. This is a very user-friendly way of retrieving the coordinates. The hardware, however, is not at all user-friendly. The goal of this prototype was not to make a product for the end user, but rather to test the components and software | side. The device can be physically made more user-friendly by making the device smaller and self-contained (no computer required).
The environmental impact should be kept low | All the components used in this prototype is RoHS compliant and is thus free of certain hazardous substances such as lead. | Fewer components can be used to decrease steps in production that create hazardous by-products (like soldering)
Cost should be as low as possible | The prototype cost R947.89 to make. | The cost can be minimized by creating a custom PCB with only the required components (no Arduino or breakout boards only the components that are essential for the device to function) on it.
Repair and upgradability | The device can easily be repaired and upgraded as it is built on a breadboard. | No improvements can be thought of at this moment

Second Prototype
1. Introduction
The goal of the second prototype is to get rid of the Arduino and replace it with a standalone MCU, the ATMega328p-pu (the same MCU used in the Arduino UNO). The reason for removing the Arduino is to save space and reduce the number of off the shelf components (that cost expensive) so that it can be easily manufactured. The MCU aspect of this prototype will be used in making the final prototype.
This prototype will not make any changes to the software and thus there is no software part of this prototype, to see how the software works refer to page 10. The usage will also remain the same and can be found on page 11.
2. Materials / Components Chosen
This prototype repurposes the components used in the previous prototype. The same GSM and GPS module is used. The Arduino UNO’s microcontroller was removed and reprogramed using a second Arduino UNO as an ISP (in-system programmer).

3. Cost
This prototype would have cost R
Component | Supplier | Cost per unit
Atmega328p-pu | Mouser | R 32.34
SIM800L Breakout | Communica | R 236.84
FGPMMOPA6H Breakout | Communica | R 635.95
| Total: | R 905.13
4. Replacing the Arduino with a Standalone MCU
Getting rid of the Arduino was quite straightforward. Arduino has a great tutorial on their website on how to use an Arduino as an ISP to burn a bootloader onto a new MCU. Although the MCU used in this prototype already had the Arduino bootloader burned to the flash, it required an external 16MHz oscillator (the ATMega328p) which has an 8MHz internal oscillator that can be used instead of an external oscillator by changing some of the MCU’s fuse bits. This way 3 more components could be removed from the board (the crystal and 2 18pF ceramic capacitors). The board profile that was used to change the bootloader can be found on Arduino’s website (find the link in the references). See the figure below on how the Arduino was used as ISP to burn a new bootloader to the MCU.

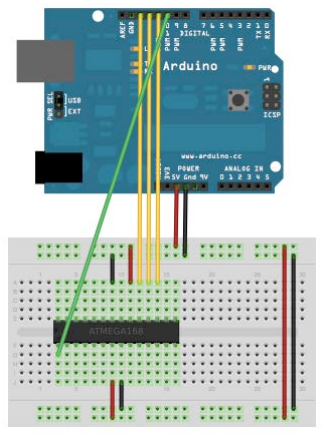
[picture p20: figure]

Figure 10 Arduino as ISP (Arduino, n.d.)
After the bootloader was burned onto the MCU, programs could easily be uploaded to the MCU using an USB-to-TTL FTDI chip that is connected to the serial port of the MCU. To save cost the Arduino board’s FTDI chip was used to program the ATMega instead of purchasing a new USB-to-TTL board.
The serial connections (RX and TX of the modules) between the MCU and the GSM and GPS modules also had to be rewired as the Arduino has been removed. The bootloader on the MCU works in the exact same way as the bootloader on the Arduino’s MCU and rewiring is a simple case of figuring out where which input/output pin connects to the MCU’s pins. This could have been done manually by using the continuity tester on a multi-meter and checking to which output the MCU’s pins connected or alternatively by using the following diagram seen below of the ATMega168 and ATMega328p’s Arduino pinout that has been pre-tested. This was the route followed in this project.

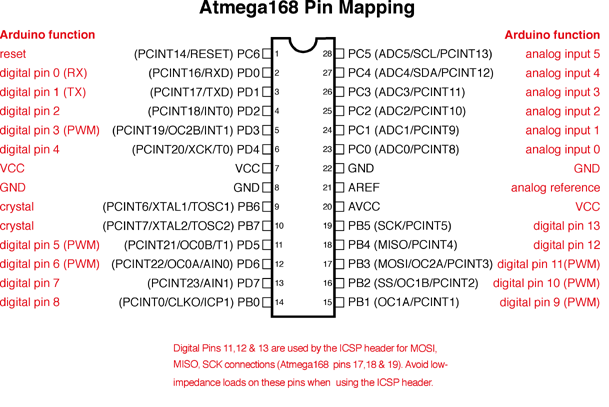
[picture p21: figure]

Figure 11 Atmega328p and 168 Arduino Pin Mapping (Arduino, n.d.)
5. Schematic and Breadboard Layout
The following two figures show the design of the second prototype and was created using Fritzing, a free open-source software that allows you to digitally make your own schematic and breadboard layout.
During the design phase, a feature was omitted (the GPS off feature) and was only noticed after the completion of the final prototype and can thus not be changed. This can be reimplemented in a later prototype.
The design does not include the VCC and GND input, but this input can be seen in the figures in the assembly section of the second prototype.

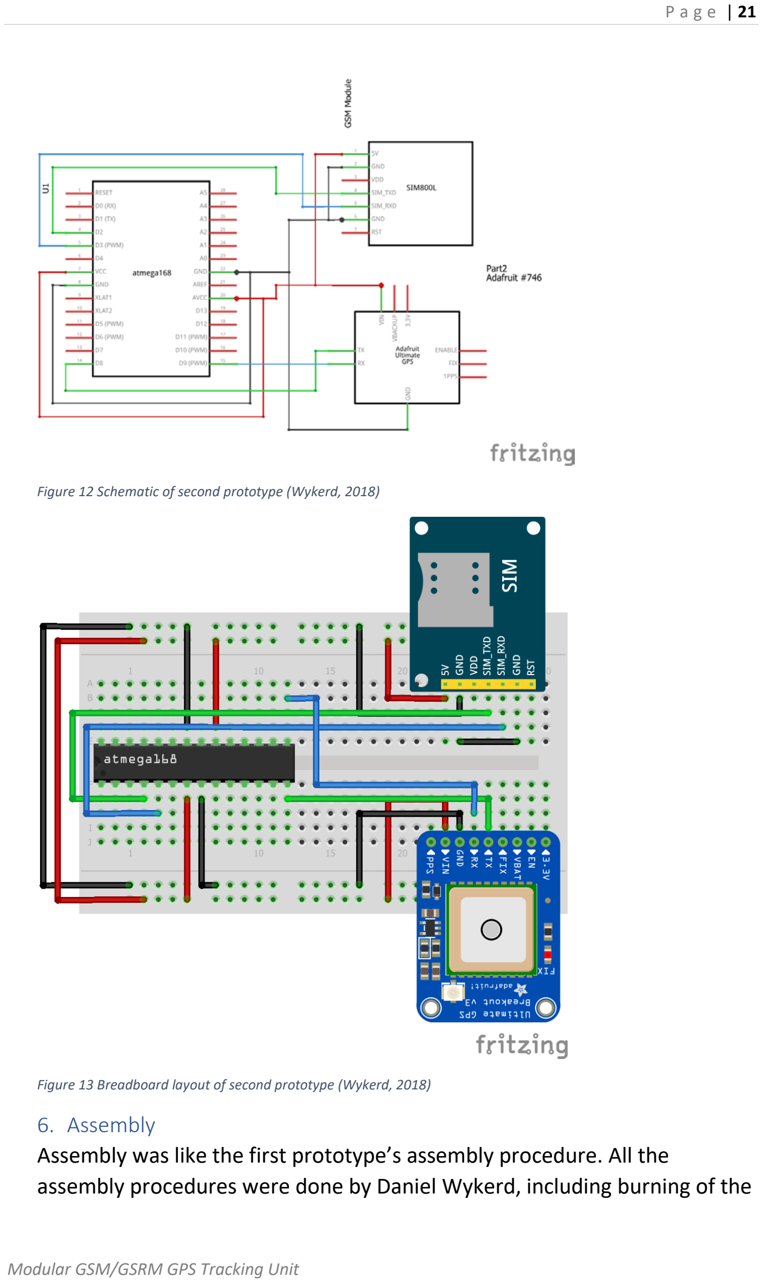
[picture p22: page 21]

Figure 12 Schematic of second prototype (Wykerd, 2018)

Figure 13 Breadboard layout of second prototype (Wykerd, 2018)
6. Assembly
Assembly was like the first prototype’s assembly procedure. All the assembly procedures were done by Daniel Wykerd, including burning of the bootloader to the MCU, programming of the MCU and wiring of the components on the breadboard. The figures below show the results.

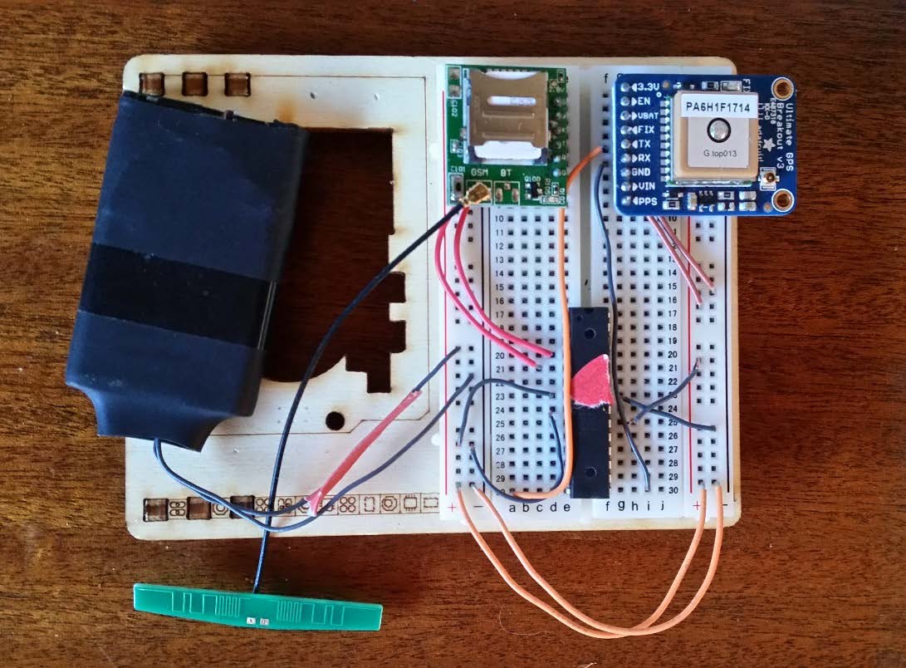
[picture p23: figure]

Figure 14 Final assembly of second prototype (Wykerd, 2018)
Power is supplied in parallel to all components. The power source is a 3.7 V Lithium Ion Polymer (Li-Po) battery salvaged from an old cell phone.

7. System diagram

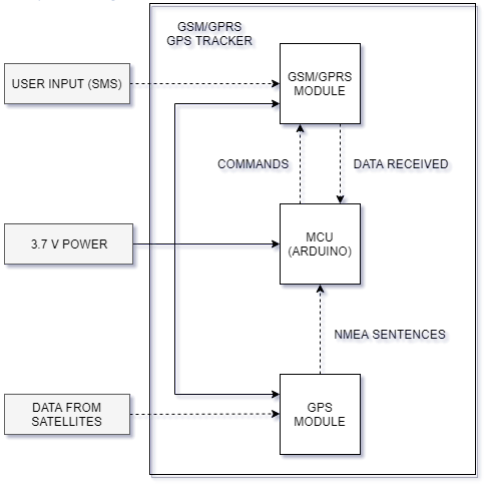
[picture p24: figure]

Figure 15 System diagram of second prototype (Wykerd, 2018)
8. Analysis of prototype
The prototype was analyzed using the design requirements and criteria outlined in the research plan to determine how well the project succeeds in the engineering goal on page 3.
Requirements
This prototype met more of the requirements than the first but still has plenty of shortcomings since it is still on a built breadboard and was not meant to be used by an end-user. The device is still not easily mass producible and is still not user-friendly in terms of hardware. The device however now runs from a single battery unlike the first prototype and has fewer parts lowering the cost.

Criteria

Table 3 Analysis of second prototype to design criteria

Criterion | How well does the device meet the criterion? | Suggested improvements that can be made:
The device should draw a low current to prolong the battery life. | The device draws a low current. The average amp draw is around 50 - 60 mA max. | There are not many improvements that can be made except that the ‘#off’ command can be reimplemented.
The device should have a small form factor | The device has a footprint of approx. 5.5cm*8.5cm*2cm. It meets the criterion poorly but better than the first prototype. | The device’s size can be diminished several times by creating a custom PCB with only the bare minimum components
The device should be user-friendly. | The device’s location can be accessed via SMS. The full list of commands can be found under ‘usage of the device’ on page 10. This is a very user-friendly way of retrieving the coordinates. The hardware, however, is not at all user-friendly, but the goal of this prototype was not to make a product for the end user but to remove the Arduino in preparation for designing the final PCB | At this moment no improvements can be made to make the device more user-friendly on the software side. The device can be physically made more user-friendly by creating a custom PCB with only the bare minimum components
The environmental impact should be kept low | All the components used in this prototype is RoHS compliant and is thus free of certain hazardous substances such as lead. | Fewer components can be used to decrease steps in production that create hazardous by-products (like soldering)
Cost should be as low as possible | The prototype cost R905.13 to make. | The cost can be minimized by creating a custom PCB with only the required components (no Arduino or breakout boards only the components that are essential for the device to function) on it.
Repair and upgradability | The device can easily be repaired and upgraded as it is built on a breadboard. | No improvements can be thought of at this moment

The Third Prototype
1. Introduction
This prototype will use all the designs made and results obtained in the previous two prototypes to create a fully functional, self-contained Modular GSM/GPRS GPS Tracker.
The device will be contained on a single multi-layered PCB designed from scratch using the chips’ datasheets as a reference during the components choosing and design stage. The reason for creating a custom PCB is so that the device can be easily manufactured as PCB fabrication is a very fast process.
There will be no off the shelf components used in the build resulting in a steep drop in the price per unit (especially if the device is made in large quantities where the components are brought in bulk). All the components used will be SMT (Surface Mount Technology) components, because these components are much smaller than their through-hole counterparts and these types of components are the most common type components used in factories. All the items can be purchased straight from the component manufactures and assembled by pick and place machines (a piece of equipment used in factories to automatically apply solder paste and thereafter the SMT components on the unpopulated boards) in factories, minimizing the need for human involvement in production (which will further decrease production cost). It will be possible for the entire device to be assembled in one factory (except for the bare components which will be sourced from suppliers).
A case will also be designed to house the device. The case will offer means of mounting the device to other modules.
2. Choosing the Main Components:
There was decided on using similar components as the components used in the previous two prototypes as these components were already tested to work with the software and hardware configuration.
The MCU chosen is the Atmega328P-AU, the same IC as the Atmega328P-PU but in a different package, TQFP (Quad flat package) instead of DIP package (Dual in-line package). The reason for choosing this component is because it has enough flash memory for the software (as the software is quite large due to the use of libraries) and is the same chip as the one used in the previous two prototypes.
The GSM/GPRS Module chosen is the SIM800C module, this chip is like the SIM800L module used in the previous prototypes but has an easier to solder package, it has its contacts around the chip instead of under the chip in a land grid array (LGA) package. This makes it easier to solder the component. Another advantage of the SIM800C is its size is 17.6*15.7*2.3mm according to its datasheet (SIMCom Wireless Solutions, 2017) in comparison to 15.8*17.8*2.4 mm (SIMCom, 2015). It does not have any unnecessary features like Bluetooth like the SIM800H has. It is thus a better module to use in this case.
The FGPMMOPA6H has been chosen as it has already been used in the other two projects. It served its purpose nicely and is thus used again in this prototype.
3. Breakdown of Schematic
The schematic for this prototype was created in EasyEDA a free online CAD software for schematic and PCB layout creation.
The schematic is broken into three parts: The GPS Module, MCU and GSM Module.
The full schematic can be found in Appendix C.
All resistors, MLCCs (Multi-Layer Ceramic Capacitors) and Tantalum capacitors are 1206 packages.
The GSM Module
The GSM module was designed first using the SIMCOM800C Datasheet listed in the references and added in the journal. Below is an image of this section.

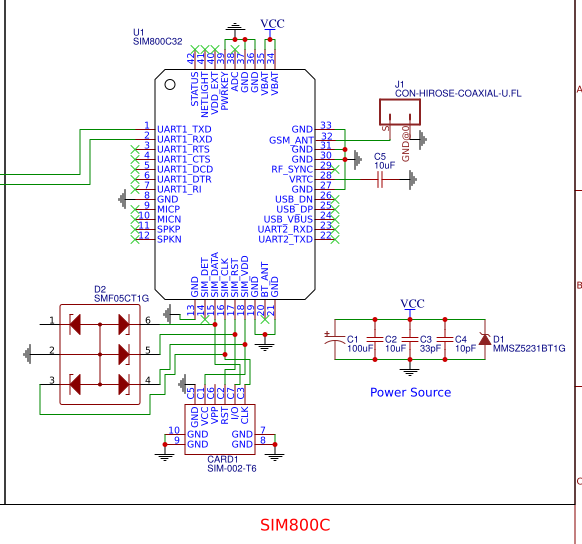
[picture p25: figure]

Figure 16 GSM Section of Schematic
The power source was designed using page 17 of the datasheet as reference.
SIM-002-T6 was chosen as the sim card reader (CARD1) as it has a push to insert and push to eject mechanism. This mechanism works the best with the case that was designed to house the PCB as the SIM can easily be ejected.
The purpose of the diode bridge SMF05CT1G (D2) is to prevent electrostatic discharge (ESD) whilst the SIM is inserted. It can be omitted but is there to protect the GSM module.
The GSM antenna will connect to the GSM module via the coaxial jack (J1). The GPS Module
The GPS module’s datasheet can be found in this project journal and in the references. Here is a breakdown of the components used:

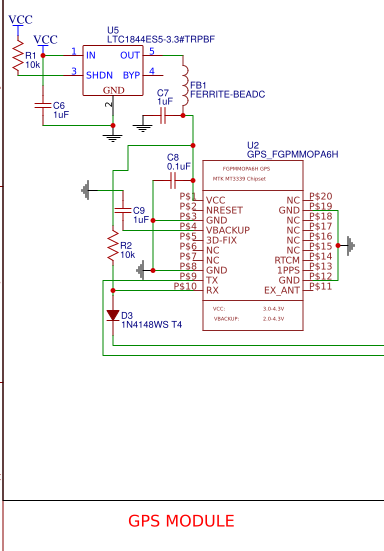
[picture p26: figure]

Figure 17 GPS Section of Schematic
U5: The GPS module has a typical voltage input of 3.3 V. The datasheet recommends a voltage regulator to keep the voltage supplied to the module constant. Microchip’s MIC2552-3.3 Low Dropout Regulator (LDO) was chosen to provide power to the module – the schematic shows another LDO, but this is because the MIC2552 was not in EasyEDA’s library of components.
R1: Keeps the LDO powered on.
FB1: The ferrite bead is used to minimize EMI (Electromagnetic Interference). This is called an RF Choke. It does not let high frequencies through. It has an impendence of 600Ohm at 100MHz according to its datasheet (Murata, n.d.). This is the same as the specs of the ferrite bead recommended by the GPS module’s datasheet.
R2 and D2 restrict the Rx input to 3.3V according to Adafruit’s reference (Adafruit Industries, 2012).

The MCU
The MCU is the same as the one used in the previous prototypes. Wiring is thus similar. Below is the schematic:


Figure 18 MCU Section of schematic
P1: Male header used for burning bootloader to MCU and programming the MCU. Also used for debugging via serial. The header can also be used by other modules to add functionality to the device as there is 3 extra digital I/O pins available for use by an external device (software update required for modules to take advantage of the MCU’s extra pins).

4. Bill of Components (BOM)
Table 4 BOM of third prototype
value | quantity package | | componen Supplier | | ManufactureManufacturer Part
SIM800C32 | 1 SIM800C | | U1 | LCSC | SIMCOM | SIM800C32
GPS_FGPMMOPA6H | 1 FGPMMOPA6H | | U2 | Adafruit | | FGPMMOPA6H
ATMEGA328P-AU | 1 TQFP-32_7X7X08P U4 | | | MOUSER | MICROCHIP ATMEGA328P-AU
10uF | 2 | 1206 C2,C5 | | LCSC | | ?
10pF | 1 | 1206 C4 | | MOUSER | | ?
33pF | 1 | 1206 C3 | | LCSC | | ?
MMSZ5231BT1G | 1 SOD-123 | | D1 | MOUSER | ON | MMSZ5231BT1G
SMF05CT1G | 1 SOT-363 | | D2 | LCSC | ON | SMF05CT1G
CON-HIROSE-COAXIAL-U.FL | 1 CON-U.FL | | J1 | MOUSER | | ?
MIC2552-3.3 | 1 TSOT-23-5 | | U5 | LCSC | MICROCHIP MIC2552-3.3
10k | 2 | 1206 R1,R2 | | LCSC | | ?
1uF | 3 | 1206 C6,C7,C9 | | LCSC | | ?
0.1uF | 1 | 1206 C8 | | MOUSER | | ?
1N4148WS T4 | 1 SOD-323 | | D3 | LCSC | CJ | 1N4148WS T4
2*6P header | 1 HDR-6X2H/2.54 | | P1 | LCSC | BOOMELE | 2*6P header
100uF | 1 CASE-A_3216 | | C1 | LCSC | | ?
FERRITE-BEADC | 1 | 1206 FB1 | | MOUSER | Murata | ?
The total cost of the project can be viewed in Appendix A.
5. PCB Layout
The PCB layout was designed in EasyEDA a free web-based CAD software for creating schematics and PCBs.
The first attempt at designing a PCB was unsuccessful as traces were not matching the right places. This failed attempt is in the journal.
Below is a figure of top PCB layer:


Figure 19 Top Layer of PCB
The GSM module, jack and GPS module will be mounted on the top layer.


Below is a figure of the bottom layer:

Figure 20 Bottom Layer PCB Layout
The MCU, Card reader, and most VCC lines will be mounted to the bottom layer.
Below is a figure of the board with all layers:

Figure 21 PCB Layout


6. System Diagram

Figure 22 System Diagram of final prototype
7. Case design
A case was designed for the PCB to fit in. The case was designed in 123D Design, a free CAD software.

Figure 23 Top view of case


Figure 25 Front view of case


The case has grooves on the sides for other modules to slide onto. The Second rectangle with the hole in goes on top of the case after the PCB and antenna is inserted into the case. The small rectangle in the lower end of the top view is a cap for the SIM slot. It is pushed into the sim hole after the sim card is installed in the slot to prevent dust and other materials from damaging the PCB. The case is not water resistant!
Here are the dimensions of the top view


Figure 26 Dimensions of Top view of case
The case is approx. (the headers add height) 22 mm high after the PCB is inserted.

Figure 24 Right view of case

8. Assembly
Assembly required special equipment and knowledge of SMT soldering. Thus, Johann Erasmus was asked to assist with soldering during the first attempt of assembling the prototype. He soldered the board under a microscope using the schematic as a reference. The GPS module was left out to test the MCU and GSM module first. It turned out that the MCU got bricked or fried while attempting to burn the bootloader to the fuses of the MCU. Johann Erasmus and Danie Ludick (PhD) assisted with debugging but no solution was found. Below is a figure of the bricked board:


Figure 27 Faulty board


After consulting with Dr. Ludick it was decided to take the PCB and parts to the University of Stellenbosch for them to populate/solder a new board. This time a 10K Ohm pull up resistor was added between VCC and reset to prevent the board from resetting. After this component was added, the bootloader did burn to the MCU. Here is a picture of the final board:

Figure 29 Top of Assembled PCB

A makeshift programming station was built by Daniel Wykerd to program and debug the board via serial. Below is an image of the programmer:

Figure 30 Programming Station

Figure 28 Bottom of Assembled PCB

9. Software
The software is the same as the software of the first two prototypes except for losing the ‘#Off’ command. The final software is available in Appendix D.
10. Analysis of results
The prototype was analyzed using the design requirements and criteria outlined in the research plan to determine how well the project succeeds in the engineering goal on page 3.
Requirements
The device meets all the requirements set out in the research plan.
The device is easily manufacturable because the device is contained on a single multi-layered PCB thus the device can be easily manufactured as PCB fabrication is a very fast process.
There is no off the shelf components used in the build resulting in a steep drop in the price per unit (especially if the device is made in large quantities where the components are brought in bulk). All the components are SMT components. These types of components are the most common type components used in factories, it can easily be assembled by pick and place machines minimizing the need for human involvement in production (which further decreases production cost). It is possible for the entire device to be assembled in one factory (except for the bare components which need to be sourced from suppliers).
The device uses pre-existing communication infrastructure, it uses SMS to communicate with the user. Thus, it does not require a subscription to a third party. Airtime can be loaded onto the SIM card and the device will work.
The device is modular. The code can be changed using the serial interface of the MCU and there are 3 digital I/O pins available for use by other modules added later. The case can easily be slid into other modules using the grooves on the sides.
The device has a battery life of over 48 hours on a 2350 mAh according to tests done. The raw data of the test can be found in the journal of the project.
The cost per unit is far below R1000 (R293.47 to be precise).

Criteria
Criterion | How well does the device meet the criterion? | Suggested improvements that can be made:
The device should draw a low current to prolong the battery life. | The device draws a low current. The average amp draw is around 50 mA max. It lasts longer than 48 on a charge of a 2350 mAh battery | There are not many improvements that can be made except that the ‘#off’ command can be reimplemented.
The device should have a small form factor | The device has a footprint of 50.1 mm * 21.1 mm * 8.4 mm. It meets the criterion extremely well. | The GSM antenna can be put on the same PCB
The device should be user-friendly. | The device’s location can be accessed via SMS. The full list of commands can be found under ‘usage of the device’ on page 10. This is a very user-friendly way of retrieving the coordinates. The hardware is very user-friendly especially if it is in a case. The device is sturdy, and it is very easy to add modules | At this moment no improvements can be made to make the device more user-friendly on the software side. The device can be physically made more user-friendly by creating more modules for the device.
The environmental impact should be kept low | The prototype uses lead solder which is a hazardous substance. | The board can be made RoHS compliant by using lead-free solder.
Cost should be as low as possible | The module cost only R293.47 to make. This is a huge improvement above the previous prototypes | The cost can be reduced by buying items in bulk
Repair and upgradability | The device uses SMT components which is not easily replaceable. The case is made of plastic and can be manufactured for cheap and replaced easily Software, however, can easily be upgraded to make the device work with different modules or fix bugs (if any are found) | It can be made easier to replace broken components

Discussion
A lot of results has been obtained in this project. The discussion will point out patterns in the results and explain it. The device’s limitations will also be discussed.

Each revision (prototype) of the device met the design requirements and criteria better than the its predecessor following reasons:
With each prototype, a significant decrease in the size of the device occurred. This is because as later prototypes were developed, the components used for testing the device became unnecessary and thus more of the components were omitted with each design revision leading to a smaller form factor.
The current draw of the device also decreased with each prototype as the unnecessary power-hungry components were removed.
The device has several limitations. The first is that the device can only get a GPS fix if it is outside. If the device is switched on inside a building it will not get a GPS fix unless it is placed near a window or somewhere with a clear line of sight with the GPS satellites. The device will function indoors if an initial GPS fix was gained outside.
The other limitation is the battery life that can be improved in later software updates by reimplementing the GPS off feature to preserve power. Another possible solution that could be researched is to add an off switch to the battery module.
Further research that can be done and improvements that can be made in the future includes designing some supporting modules like battery modules or modules that allow attachment of the device to objects. Another version of the software could be created that constantly streams the device’s location to a data server like a MySQL server, allowing the user to view a log of where the device was using the web. The device already supports uploading to the internet and has 2G network support thus this feature can easily be added in the future. The GSM antenna can be put onto the PCB making the assembly process easier.
Conclusion
The Modular GSM GPS Module designed and manufactured in this project meets the requirements and criteria set out in the research plan of this project exceptionally well.
Thanks to the fact that a custom PCB was created using industry standard production techniques the module is easily manufacturable, costs only R293.47 to make and does not require a subscription to a third party. The PCB is accompanied by a great case that make the device modular, meaning features can easily be added if other companies make modules for the device that is compatible with the PCB’s pin out and case design. The PCB and case were designed in such a way that it is easy to create these modules. It shouldn’t take a company to long to produce its own module.
The device draws a low current of around 50 mA and can last over for 48 hours on a 2350 mAh battery. According to all these results obtained, it is clear that the device created meets the engineering goal of this project.
Bibliography
Adafruit Industries, 2012. Adafruit Ultimate GPS Arduino Wiring. [Online]
Available at: https://learn.adafruit.com/adafruit-ultimate-gps/arduino-wiring [Accessed 20 01 2018].
Adafruit Industries, 2012. Learn Adafruit Ultimate GPS Downloads. [Online] Available at: https://learn.adafruit.com/adafruit-ultimate-gps/downloads [Accessed 5 5 2018].
Arduino, n.d.. ArduinoToBreadboard. [Online]
Available at: https://www.arduino.cc/en/Tutorial/ArduinoToBreadboard [Accessed 13 04 2018].
Arduino, n.d.. Reference GSM Library. [Online]
Available at: https://www.arduino.cc/en/Reference/GSM
[Accessed 06 02 2018].
Arduino, n.d.. Standalone Atmega. [Online]
Available at: https://www.arduino.cc/en/uploads/Hacking/Atmega168PinMap2.png [Accessed 13 4 2018].
Murata, n.d.. Chip Ferrite Bead. [Online]
Available at: https://www.mouser.co.za/datasheet/2/281/QNFA9105-1130343.pdf [Accessed 8 5 2018].
SIMCom Wireless Solutions, 2017. SIM800C Hardware Design. [Online]
Available at: http://simcom.ee/documents/SIM800C/SIM800C_Hardware_Design_V1.05.pdf [Accessed 8 5 2018].
SIMCom, 2015. SIM800H&SIM800L Hardware Design. [Online]
Available at:
http://simcom.ee/documents/SIM800H/SIM800H%26SIM800L_Hardware%20Design_V2.02.pdf [Accessed 8 5 2018].
SIMCom, 2016. SIM808 Hardware Design. [Online]
Available at: http://simcom.ee/documents/SIM808/SIM808_Hardware%20Design_V1.03.pdf [Accessed 5 5 2018].
South African Police Service, n.d.. SAPS Crime Statistics. [Online]
Available at: https://www.saps.gov.za/services/crimestats.php
[Accessed 28 April 2018].

Stats SA, 2017. Statistical Release P0341. [Online]
Available at: https://www.statssa.gov.za/publications/P0341/P03412016.pdf [Accessed 28 April 2018].
TrackTheWorld, n.d.. TRACKERS: MULTI-PURPOSE. [Online]
Available at: http://www.trackingtheworld.com/products/multipurpose.php [Accessed 28 April 2018].
Wikipedia, 2018. Global Positioning System. [Online]
Available at: https://en.wikipedia.org/wiki/Global_Positioning_System [Accessed 06 May 2018].
Wikipedia, 2018. Microcontroller. [Online]
Available at: https://en.wikipedia.org/wiki/Microcontroller
[Accessed 6 May 2018].
Wykerd, D., 2018. Assembly of first prototype. [Art].
Wykerd, D., 2018. Breadboard layout of first prototype. [Art]. Wykerd, D., 2018. Case designs. [Art].
Wykerd, D., 2018. Example of the serial output. [Art]. Wykerd, D., 2018. Format of #Location. [Art].
Wykerd, D., 2018. Image of first prototype components. [Art].
Wykerd, D., 2018. Photo of second prototype assembly. [Art].
Wykerd, D., 2018. Photos of final prototype. [Art].
Wykerd, D., 2018. Schematic and breadboard layout of second project. [Art]. Wykerd, D., 2018. Schematic of first prototype. [Art].
Wykerd, D., 2018. System diagrams. [Art].
Wykerd, D., 2018. Test Wiring of SIM800L. [Art].

Acknowledgments
Thanks to Rochelle and Malan Wykerd for funding this project.
Thanks, Johann Erasmus for soldering the first attempt at assembling the final prototype and helping with the debugging of the final prototype’s first attempt.
Thanks to Dr. Danie Ludick (PhD) for organizing with the University of Stellenbosch to populate the final prototype, reading through my designs and helping to debug the first attempt to assemble the first prototype. Unpopulated PCBs fabricated by JLCPCB.

Appendix A
Table 5 Total cost of project
Component/Apperatus | Quantity SUPPIER | | PRICE PER UNIT | TOTAL
GPS MODULE BREAKOUT | 1 COMMUNICA | | 635.96 | 635.96
GSM MODULE BREAKOUT | 1 COMMUNICA | | 236.84 | 236.84
PCBS | 10 JLCPCB | | 2.2 | 22
ATMEGA328P-AU | 2 MOUSER | | 27.28 | 54.56
MIC2552-3.3YM5TR | 2 MOUSER | | 5.29 | 10.58
U.FL-R | 2 MOUSER | | 11 | 22
MLCC 10PF | 5 MOUSER | | 4.51 | 22.55
MLCC 0.1UF | 5 MOUSER | | 8.24 | 41.2
FERRITE BEAD | 5 MOUSER | | 3.17 | 15.85
MLCC 33PF | 100 LCSC | | 0.4 | 40
1N414WS | 50 LCSC | | 0.16 | 8
SMF05CT1G | 2 LCSC | | 2.01 | 4.02
TANTALUM 100UF | 5 LCSC | | 2.93 | 14.65
HEADER | 10 LCSC | | 0.58 | 5.8
MMSZ5231BT1G | 20 LCSC | | 0.48 | 9.6
SIM800C32 | 2 LCSC | | 61.92 | 123.84
MLCC 10UF | 10 LCSC | | 0.69 | 6.9
MLCC 1UF | 20 LCSC | | 0.84 | 16.8
SIM-002-T6 | 2 LCSC | | 7.238 | 14.476
CHIP RESISTOR 10K OHM | 50 LCSC | | 0.18 | 9
| | SUB TOTAL | 1011.918 | 1314.626
| | | SHIPPING COSTS | 960
| | | TOTAL | 2274.626

Appendix B

THE CODE WITH THE GPS OFF FEATURE IS ON THE NEXT TWO PAGES:

Appendix C

Appendix D

THE CODE WITHOUT THE GPS OFF FEATURE IS ON THE NEXT TWO PAGES:

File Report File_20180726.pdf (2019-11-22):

Modular GSM/GSRM GPS Tracking Unit

## MODULAR GSM GPS TRACKING UNIT

### ESKOM EXPO REPORT FILE

### DANIEL WYKERD

10A3

10 MEI 2018

Contents

The GSM Module | 26
The GPS Module | 27
The MCU | 29
4. Bill of Components (BOM) | 30
5. PCB Layout | 30
6. System Diagram | 32
7. Case design | 32
8. Assembly | 34
9. Software | 36
10. Analysis of results | 36
Requirements | 36
Criteria | 37
Discussion | 37
Conclusion | 38
Bibliography | 39
Acknowledgments | 40
Appendix A | 41
Appendix B | 42
Appendix C | 43
Appendix D | 44

Figure Index
Figure 1 Image of the main components (Wykerd, 2018) | 9
Figure 2 Picture of Ultimate GPS Wiring for testing (Adafruit Industries, 2012) | 10
Figure 3 Wiring of the SIM800L module to communicate with the computer (Wykerd, 2018) | 10
Figure 4 Schematic of first prototype (Wykerd, 2018) | 11
Figure 5 Breadboard layout of first prototype (Wykerd, 2018) | 11
Figure 6 Image of breadboard assembly (Wykerd, 2018) | 12
Figure 7 Example of the serial output (Wykerd, 2018) | 14
Figure 8 Example of #Location SMS (Wykerd, 2018) | 15
Figure 9 System Diagram of first prototype (Wykerd, 2018) | 15
Figure 10 Arduino as ISP (Arduino, n.d.) | 19
Figure 11 Atmega328p and 168 Arduino Pin Mapping (Arduino, n.d.) | 20
Figure 12 Schematic of second prototype (Wykerd, 2018) | 21
Figure 13 Breadboard layout of second prototype (Wykerd, 2018) | 21
Figure 14 Final assembly of second prototype (Wykerd, 2018) | 22
Figure 15 System diagram of second prototype (Wykerd, 2018) | 23
Figure 16 GSM Section of Schematic | 27
Figure 17 GPS Section of Schematic | 28
Figure 18 MCU Section of schematic | 29

Figure 19 Top Layer of PCB | 30
Figure 20 Bottom Layer PCB Layout | 31
Figure 21 PCB Layout | 31
Figure 22 System Diagram of final prototype | 32
Figure 23 Top view of case | 32
Figure 24 Right view of case | 33
Figure 25 Front view of case | 33
Figure 26 Dimensions of Top view of case | 33
Figure 27 Faulty board | 34
Figure 28 Bottom of Assembled PCB | 35
Figure 29 Top of Assembled PCB | 35
Figure 30 Programming Station | 35
Table Index
Table 1 List of possible components: | 8
Table 2 Analysis of first prototype to design criteria: | 16
Table 3 Analysis of second prototype to design criteria | 24
Table 4 BOM of third prototype | 30
Table 5 Total cost of project | 41

Introduction / Problem:
A need was identified in our country for a way to retrieve stolen goods especially vehicles like cars, motorcycles, and bicycles as well as personal property.
This project will attempt to solve this problem by designing and manufacturing a modular GPS module.
The need for this device is substantiated by multiple local governmental statistical releases. In a recent document published by the South African Police Service(SAPS) it is revealed there are 53 307 cases of car and motorcycle theft and 16 717 cases of car hijacking between April 2016 and March 2017 (South African Police Service, n.d.). It is also revealed in a statistical release done by Stats SA that there were 21 051 cases of bicycle theft, 284 252 cases of money/purse/wallet theft, and 18 119 cases of bag theft in this period. (Stats SA, 2017).
During the literature study to motivate the project several pre-existing products that prevent some of these problems by using GPS Tracking or alarm systems were identified, but most of these products are dedicated devices designed to only prevent the theft of one of the above-listed items. Research done on these devices can be found in the journal of this project. This project will attempt to design a GPS unit that can be used locate any kind of stolen goods. The device will not be limited to finding only certain objects.
There are devices like TrackingTheWorld’s ‘Enduro’ series trackers that are multipurpose (TrackTheWorld, n.d.), but most of these devices don’t offer any means to hide or attach, they are clunky, have a lot of unnecessary features, are uneconomical as they cost upwards of $289.00 and are not locally available to purchase. The device designed in this project will be customizable to suit the needs of the user and will be cheap to mass produce. The main device will have no unnecessary features and will be very small and compact. Engineering Goal:
The goal of this project is to ultimately design, test, produce and manufacture a modular electronic device that uses GPS to accurately track stolen objects from anywhere in the country. The reason for designing this device is to give users an easy way to retrieve lost or stolen goods by allowing the owner of the goods to view where their goods are located at all times. The device will be modular meaning that you can connect the core tracking module to different modules to add extra functionality and uses to the device to suit the user’s needs. The device/circuity should be as small as possible – preferably smaller than an AA-battery in length – and must be mass producible. The circuit should draw a low current as to prolong the device’s battery life. There should be no third-party involved in retrieving the coordinates thus the device should use common communication infrastructure like SMS to send the coordinates to the user.
Background Study on Required Components:
To design the tracker, background knowledge of what components will be required to create the device was required. The required components were narrowed down to a microcontroller unit(MCU), which will be used to communicate with all the other components and process their data; a GSM/GPRS module, which will receive user queries (SMSs) and respond to them; a GPS module, which will get the location of the device. This study will provide the reader with background knowledge on the integrated circuits and modules used in this project. It will also explain the reason behind choosing the components.
The Microcontroller Unit (MCU)
A Microcontroller or MCU is a small computer contained on a single integrated circuit (IC). A microcontroller contains one or more processing cores along with memory and programmable input/output peripherals (Wikipedia, 2018).
The MCU will interface with all the other core components of the device, including the GPS and GSM module. It will interpret user input from the GSM module, process the data from the GPS module and output code back to the GSM module to send the location of the device back to the user.
There are plenty of microcontrollers on the market, but the decision was made to use an Arduino as the microcontroller (MCU) for the first prototype. This decision was made because the project leader (Daniel Wykerd) already had experience using Arduino and its IDE. Another deciding factor was the fact that Arduino is open source hardware. There was also decided to make use of an Atmel MCU with an Arduino bootloader burned on it for later prototypes as their MCUs are Arduino compatible. Research was done on multiple ATMega and ATTiny MCUs (all of which are listed in my journal) but there was decided that the ATMega328p MCU was the best option as it is the same MCU used in most Arduino boards, thereby making the design and testing process much easier as this MCU is very well documented online.
The GSM/GPRS Module
The GSM Module is the part of the device that will receive the user queries and will send back the response to the user. It uses a sim card and gsm antenna to connect to pre-existing mobile providers (e.g. Vodacom).
The prime requirement for the module is to be able to send and receive SMSs. Two companies were found during the study that makes modules that meet this requirement: Quectel and SIMCom. Both these companies were well documented, but further research into local availability revealed that Quectel was not readily available in the form of development boards (boards that already have all the support circuitry), thus SIMCom modules were chosen as they were widely available for purchase on development/breakout boards. It was necessary for the modules to be on breakout boards to create the first prototype on a breadboard for testing. There was decided on 3 possible modules: SIM808, SIM800L/H, SIM800C. The SIM808 seemed like a good choice as according to its datasheet it has GPS functionality built in, but it does not have an integrated patch antenna (SIMCom, 2016). The SIM800L/H was also considered as it is readily available on breakout boards and has all the features required and more, however this chip would not be usable for the final prototype as it comes in an LGA (Land Grid Array) package which can only be reflow soldered. Thus, it was considered to use the SIM800C in the final prototype. The SIM800C has less unnecessary features and more importantly, it has an easier to solder SMT layout.
The GPS Module
According to Wikipedia.org, “The Global Positioning System (GPS), originally Navstar GPS, is a satellite-based radio navigation system owned by the United States government and operated by the United States Air Force. It is a global navigation satellite system that provides geolocation and time information to a GPS receiver anywhere on or near the Earth where there is an unobstructed line of sight to four or more GPS satellites. Obstacles such as mountains and buildings block the relatively weak GPS signals.” (Wikipedia, 2018).
There was decided on using the GlobalTop Technology Inc.’s FGPMMOPA6H GPS Module as it has an integrated patch antenna which will result in a smaller PCB footprint in the final prototype and fewer costs. The module is also used in Adafruit’s Ultimate GPS module and is well documented on their website. The module outputs its data as NMEA Sentences that can easily be read and interpreted by the MCU
Main Materials / Core Component list:
Below is a breakdown of the components that can possibly be used as well as their prices and what suppliers can be used to purchase them from:

Table 1 List of possible components:
Component | Options | Suppier | Cost
Microcontroller | Arduino UNO/PRO MINI Communica | | R 75.00
| ATMega328p-au | Mouser | $2.48
GSM/GRSM Module | SIM808 | Adafruit | $29.90
| SIM800L/H | Communica | R 236.84
| SIM800C | LCSC | $5.63
GPS Module | FGPMMOPA6H | Communica | R635.95
First Prototype:
1. Introduction and Materials Chosen
The goal of the first prototype was to test the concept of making a tracker and to ensure that all the picked components worked properly, thus the components were brought in the form of breakout boards for easy assembly.
Due to the time constraints of this project, the components for the first prototype had to be purchased locally. Thus, Communica was used as the supplier of parts for this prototype. A SIM800L breakout board and Ultimate GPS module (FGPMMOPA6H) module were purchased from them. An Arduino UNO was already purchased beforehand. A breadboard is also required for this prototype See Appendix A for the total cost of this project.


Figure 1 Image of the main components (Wykerd, 2018)
2. Testing the components
Before creating the first prototype the components were tested to ensure that they were in working order.
To test the GPS Module, Adafruit’s provided example code and their provided code library found on their website was used. After installing the library found on their website (Adafruit Industries, 2012), the parsing example code which can be found in the project journal on the 20th of January 2018 was used. Below is an image of the wiring:


Figure 2 Picture of Ultimate GPS Wiring for testing (Adafruit Industries, 2012)
The test for the GPS was successful and the GPS gave accurate readings. Next, the GSM module was tested via serial. It was wired like below:


Figure 3 Wiring of the SIM800L module to communicate with the computer (Wykerd, 2018)
This test was also successful. However, the module could not acquire a network connection due to insufficient power. This was solved during the designing of the first prototype by adding a 3,7 V lithium-ion polymer (Li-Po) battery to power the module.

3. Schematic and Breadboard Layout:
The following two figures show the design of the first prototype and was created using Fritzing, a free open-source software that allows you to digitally make your own schematic and breadboard layout.


Figure 4 Schematic of first prototype (Wykerd, 2018)


Figure 5 Breadboard layout of first prototype (Wykerd, 2018)
The GSM module will interface with the MCU(Arduino) by wiring the TX (Transmit) and RX (Receive) of the module and digital pin 2, which will act as the MCUs RX (going to TX of module) and 3, which has PWM (Pulse Width Modulation) to transmit commands to the module. The GPS will interface with the module by wiring the module’s RX to digital pin 9 of the MCU and the TX to digital pin 8 of the MCU. The interfacing between the modules is required as this is how all the parts will work together.
4. Assembly
The board was assembled on a breadboard using Figure 5 above as reference during the assembly. The hardware was tested beforehand in
step 2 on page 7 to decrease the chance that the prototype would fail. The final prototype is shown below in Figure 6.


Figure 6 Image of breadboard assembly (Wykerd, 2018)
The wiring of the circuit was done by hand by Daniel Wykerd as was all the other assembly procedures. There was decided on using the power that the Arduino obtained via USB connection to the computer as the power source for the Arduino and GPS Module rather than a 9V-battery.
Another feature was added to the design to allow the user to turn off the GPS module. This is accomplished by connecting the GPS module’s VCC to pin 7 of the Arduino instead of directly to the Arduino’s 5V output.

5. Software
After the hardware was designed, software had to be created for the MCU so that the device will function. This software was made using the Arduino language which is a set of C/C++ functions.
Firstly, a program that can read and respond to specific SMS commands was created and tested. To communicate with the GSM, Arduino’s GSM Library (that was preinstalled on their IDE) was used and their website utilized to gain knowledge of the functions included in the library (Arduino, n.d.). At this point, the GPS was not yet implemented into the code (this code can be found in the project journal on the 6th of February 2018).
Next, it was time to implement the GPS location. To do this Adafruit GPS library was used, but this library clashed with the functions of the GSM library. Thus, an alternative was needed: TinyGPS++, this library was much more lightweight than Adafruit’s and AltSoftSerial was also used as an alternative to the IDE’s built-in SoftwareSerial library as it also clashed with the GSM library. A revision of the code was created with these libraries and can be found in the journal on the 7th of February 2018 and later the code was further adapted to the more final code available in the journal on the 10th of February 2018.
Lastly, GPS off feature was added (the code of which is available in the journal on the 10th of March). This code was the final code for this prototype. The code can be found in Appendix B.
The software also lets the Arduino output valuable debugging information through the serial port (Rx and Tx) to the computer via USB and can be viewed using a serial monitor application (like the one built into the Arduino’s IDE). The debugging output works like follows and an example can be found in figure 7 below.
Upon applying power to the module the line “Boot” is printed to the serial port to verify that the device is indeed booting up. Once the device has registered to a network the line “OK” is printed, this means the device is ready for commands. NOTE: this does not mean the device has a GPS fix. If a message is sent to the device the following lines are printed to serial: The sender’s number; the command sent, if the message does not start with a ‘#’ the word “INVALID” will be printed to serial; The word “DEL” meaning

that the device has completed the command, deleted the message from the sim card and is ready to receive the next command.

Figure 7 Example of the serial output (Wykerd, 2018)
6. Usage of The Device
In this section, an explanation is given on how the user will retrieve the location of the device.
The user will send a command to the device via SMS, there are three possible commands the user can send to the device. The command “#Location” (not case sensitive) can be sent to the number of the sim card inside the device (the device will require a sim card loaded with airtime to send the response back) to retrieve the device’s location. The format of the SMS can be seen in Figure 8 below. The first line of the SMS includes the coordinates, the second includes a link to Google Maps that shows the location of the device on Google Maps. The last line shows the number of satellites that the GPS module has acquired, this is for debugging and to show the quality of the GPS fix. If there is no GPS fix an SMS saying “Acquiring satellites” will be sent.


Figure 8 Example of #Location SMS (Wykerd, 2018)
The command “#Help” can be sent to see a list of the possible commands that the device can react to. Lastly, the command “#Off” can be sent to turn off the GPS module to save battery life. The GPS module will automatically turn back on if the user requests the location by sending “#location” again.
7. System Diagram

Figure 9 System Diagram of first prototype (Wykerd, 2018).

8. Analysis of prototype:
The prototype was analyzed using the design requirements and criteria outlined in the research plan to determine how well the project succeeds in the engineering goal on page 3.
Requirements
Since the goal of the first prototype was to test the concept of creating a GPS Tracker and not to be reproduced, some of the requirements were not met.
The device is easily manufacturable, but only in small scale, it would be uneconomical to produce this prototype on a mass scale and the electronics of the device is not permanently attached and can easily be disassembled. This easy disassembly was necessary so that debugging can be done fast, and components can be rewired and/or replaced in a matter of seconds.

The device does not get its power from one power source, this issue is addressed in the next prototype by removing the Arduino entirely and opting for a standalone Atmel MCU.
Criteria

Table 2 Analysis of first prototype to design criteria:
Criterion | How well does the device meet the criterion? | Suggested improvements that can be made:
The device should draw a low current to prolong the battery life. | The device is powered via the USB of the computer. It does not use a battery as its primary energy source. There are measures in place to preserve power, this includes the “#Off” command that will turns of the GPS module. | This issue can be eliminated by getting rid of the Arduino and using a standalone MCU instead.
The device should have a small form factor | The device has a footprint of approx. 12cm*9.5cm*4cm. It meets the criterion very badly. | The device’s size can be cut in half by replacing the Arduino with a standalone MCU.
The device should be user-friendly. | The device’s location can be accessed via SMS. The full list of commands can be found under ‘usage of the device’ | At this moment no improvements can be made to make the device more user-friendly on the software

| on page 10. This is a very user-friendly way of retrieving the coordinates. The hardware, however, is not at all user-friendly. The goal of this prototype was not to make a product for the end user, but rather to test the components and software | side. The device can be physically made more user-friendly by making the device smaller and self-contained (no computer required).
The environmental impact should be kept low | All the components used in this prototype is RoHS compliant and is thus free of certain hazardous substances such as lead. | Fewer components can be used to decrease steps in production that create hazardous by-products (like soldering)
Cost should be as low as possible | The prototype cost R947.89 to make. | The cost can be minimized by creating a custom PCB with only the required components (no Arduino or breakout boards only the components that are essential for the device to function) on it.
Repair and upgradability | The device can easily be repaired and upgraded as it is built on a breadboard. | No improvements can be thought of at this moment

Second Prototype
1. Introduction
The goal of the second prototype is to get rid of the Arduino and replace it with a standalone MCU, the ATMega328p-pu (the same MCU used in the Arduino UNO). The reason for removing the Arduino is to save space and reduce the number of off the shelf components (that cost expensive) so that it can be easily manufactured. The MCU aspect of this prototype will be used in making the final prototype.
This prototype will not make any changes to the software and thus there is no software part of this prototype, to see how the software works refer to page 10. The usage will also remain the same and can be found on page 11.
2. Materials / Components Chosen
This prototype repurposes the components used in the previous prototype. The same GSM and GPS module is used. The Arduino UNO’s microcontroller was removed and reprogramed using a second Arduino UNO as an ISP (in-system programmer).

3. Cost
This prototype would have cost R
Component | Supplier | Cost per unit
Atmega328p-pu | Mouser | R 32.34
SIM800L Breakout | Communica | R 236.84
FGPMMOPA6H Breakout | Communica | R 635.95
| Total: | R 905.13
4. Replacing the Arduino with a Standalone MCU
Getting rid of the Arduino was quite straightforward. Arduino has a great tutorial on their website on how to use an Arduino as an ISP to burn a bootloader onto a new MCU. Although the MCU used in this prototype already had the Arduino bootloader burned to the flash, it required an external 16MHz oscillator (the ATMega328p) which has an 8MHz internal oscillator that can be used instead of an external oscillator by changing some of the MCU’s fuse bits. This way 3 more components could be removed from the board (the crystal and 2 18pF ceramic capacitors). The board profile that was used to change the bootloader can be found on Arduino’s website (find the link in the references). See the figure below on how the Arduino was used as ISP to burn a new bootloader to the MCU.


Figure 10 Arduino as ISP (Arduino, n.d.)
After the bootloader was burned onto the MCU, programs could easily be uploaded to the MCU using an USB-to-TTL FTDI chip that is connected to the serial port of the MCU. To save cost the Arduino board’s FTDI chip was used to program the ATMega instead of purchasing a new USB-to-TTL board.
The serial connections (RX and TX of the modules) between the MCU and the GSM and GPS modules also had to be rewired as the Arduino has been removed. The bootloader on the MCU works in the exact same way as the bootloader on the Arduino’s MCU and rewiring is a simple case of figuring out where which input/output pin connects to the MCU’s pins. This could have been done manually by using the continuity tester on a multi-meter and checking to which output the MCU’s pins connected or alternatively by using the following diagram seen below of the ATMega168 and ATMega328p’s Arduino pinout that has been pre-tested. This was the route followed in this project.


Figure 11 Atmega328p and 168 Arduino Pin Mapping (Arduino, n.d.)
5. Schematic and Breadboard Layout
The following two figures show the design of the second prototype and was created using Fritzing, a free open-source software that allows you to digitally make your own schematic and breadboard layout.
During the design phase, a feature was omitted (the GPS off feature) and was only noticed after the completion of the final prototype and can thus not be changed. This can be reimplemented in a later prototype.
The design does not include the VCC and GND input, but this input can be seen in the figures in the assembly section of the second prototype.


Figure 12 Schematic of second prototype (Wykerd, 2018)

Figure 13 Breadboard layout of second prototype (Wykerd, 2018)
6. Assembly
Assembly was like the first prototype’s assembly procedure. All the assembly procedures were done by Daniel Wykerd, including burning of the bootloader to the MCU, programming of the MCU and wiring of the components on the breadboard. The figures below show the results.


Figure 14 Final assembly of second prototype (Wykerd, 2018)
Power is supplied in parallel to all components. The power source is a 3.7 V Lithium Ion Polymer (Li-Po) battery salvaged from an old cell phone.

7. System diagram


Figure 15 System diagram of second prototype (Wykerd, 2018)
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

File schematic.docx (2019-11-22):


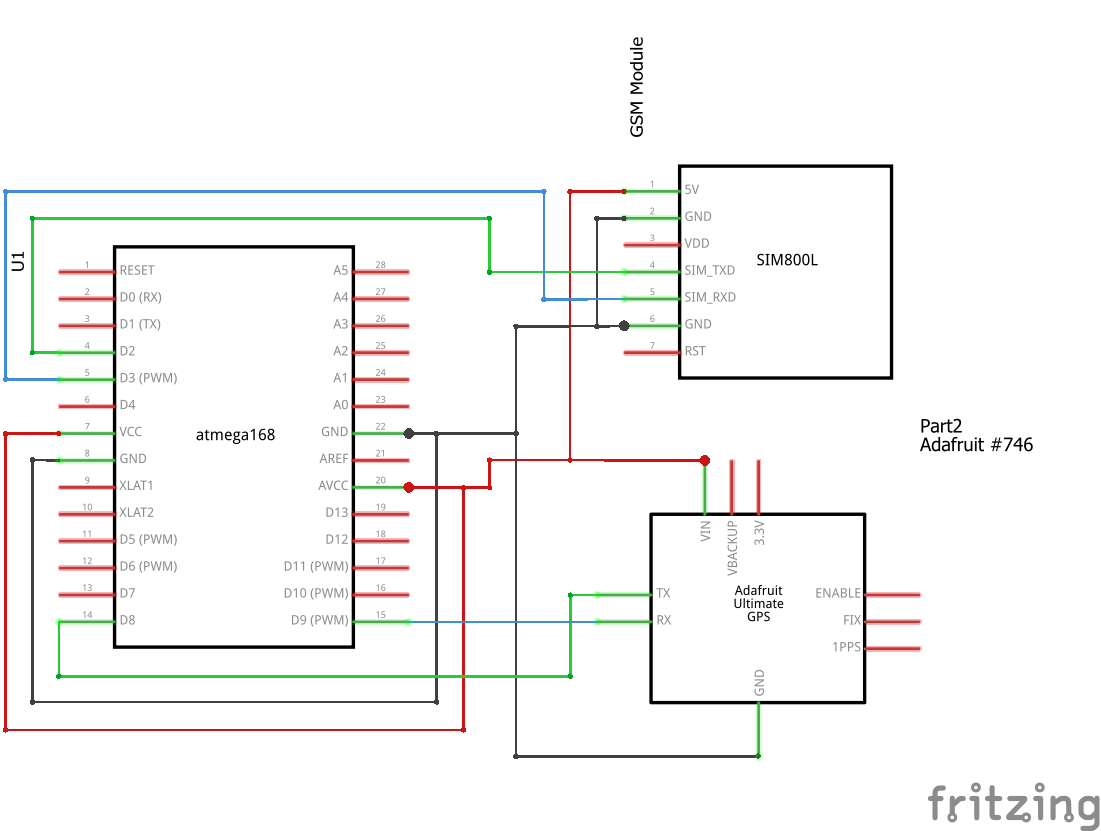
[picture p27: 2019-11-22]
PROTOTYPE 2 SCHEMATIC_schem.png

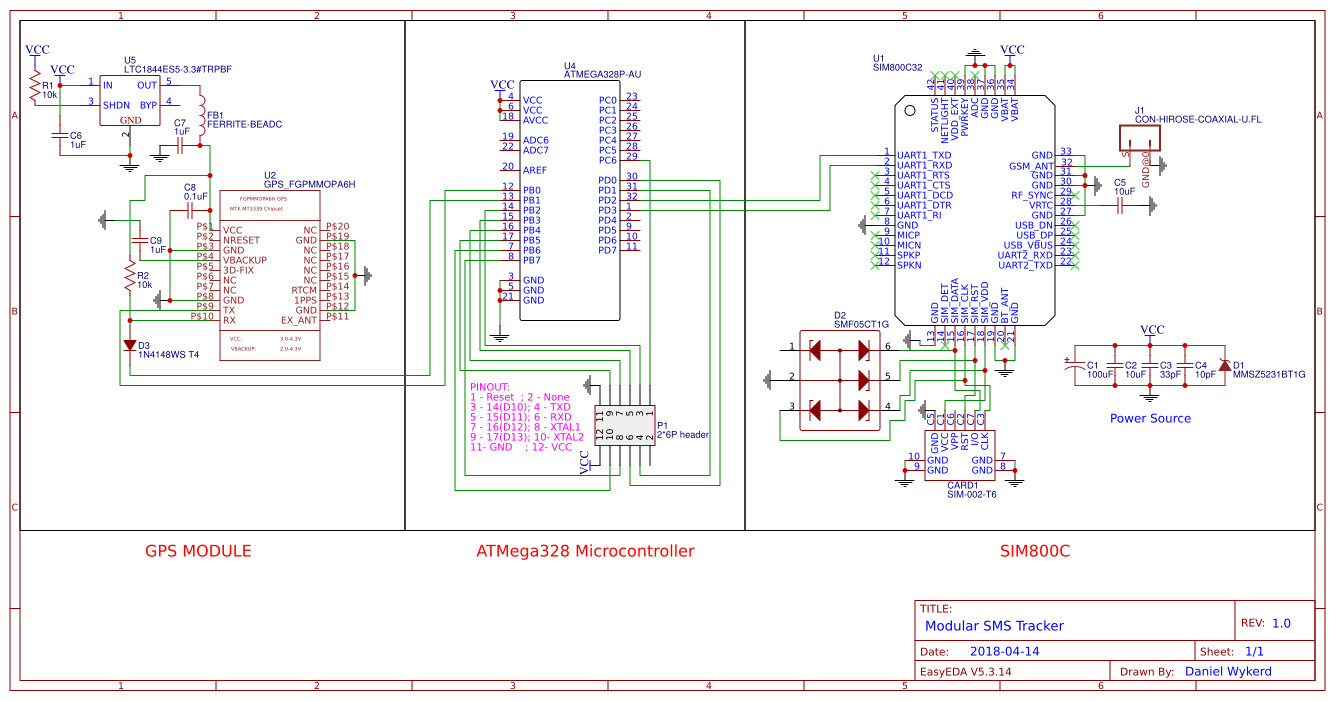
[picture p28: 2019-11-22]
Schematic_SMS-Tracker_Sheet-1_20180508195339.png

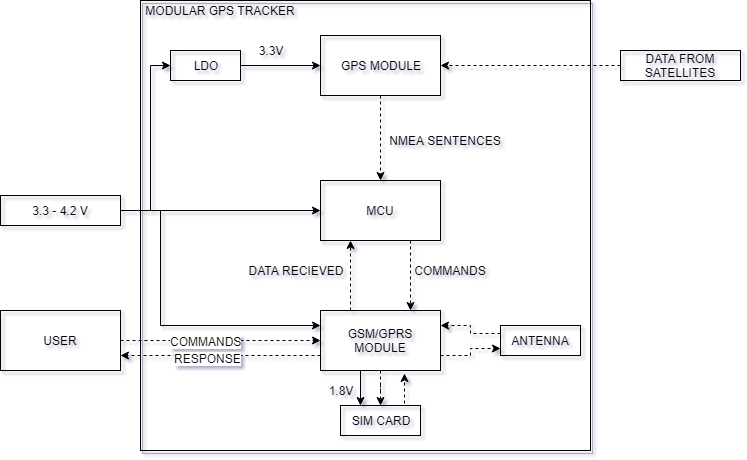
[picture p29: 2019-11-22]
Images/Hardware/SYSDIAGFINAL.png

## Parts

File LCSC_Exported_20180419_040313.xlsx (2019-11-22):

LCSC Part Number | Manufacture Part Number | Manufacturer | Package | RoHS | Order Qty. | Unit Price | Min\Mult Order Qty. | Order Price
C1886 | 1206CG120J500NT | Guangdong Fenghua Advanced Tech | 1206 | Yes | 100 | $0.0145 | 100\100 | $1.45 | 12pF, 5%, 50V, C0G/NP0 | mlcc
C1906 | 1206CG330J500NT | Guangdong Fenghua Advanced Tech | 1206 | Yes | 100 | $0.0163 | 100\100 | $1.63 | 33pF, 5%, 50V, C0G/NP0 | mlcc
C2128 | 1N4148WS | Changjiang Electronics Tech (CJ) | SOD-323 | No | 50 | $0.0142 | 50\50 | $0.71 | 100uF, 20%, 6.3V | tantalum
C15879 | SMF05CT1G | ON Semicon | SOT-363 | No | 2 | $0.1867 | 1\1 | $0.37
C27279 | TLJA107M006R0800 | AVX | CASE-A_3216 | Yes | 5 | $0.2665 | 5\5 | $1.33
C66198 | MMSZ5231BT1G | ON Semicon | SOD-123 | No | 20 | $0.0441 | 20\20 | $0.88
C69120 | SIM800C32 | SIMCom Wireless Solutions | SMD module | Yes | 2 | $5.6374 | 1\1 | $11.27
C82601 | CC1206KRX7R9BB104 | YAGEO | 1206 | Yes | 50 | $0.0399 | 50\50 | $2 | 100nF, 10%, 50V, X7R | mlcc
C92790 | JMK316BJ106ML-T | Taiyo Yuden | 1206 | Yes | 10 | $0.0626 | 10\10 | $0.63 | 10uF, 20%, 6.3V, X5R | mlcc
C111198 | SIM-002-T6 | SOFNG | Dimension：17.2mm*15.36mm*1.38mm | No | 2 | $0.6589 | 1\1 | $1.32 | 1uF, 10%, 25V, X8R | mlcc
C144471 | AC1206JR-0710KL | YAGEO | 1206 | Yes | 50 | $0.0057 | 50\50 | $0.29 | 1/4 W, 10K, 5% | chip resistor

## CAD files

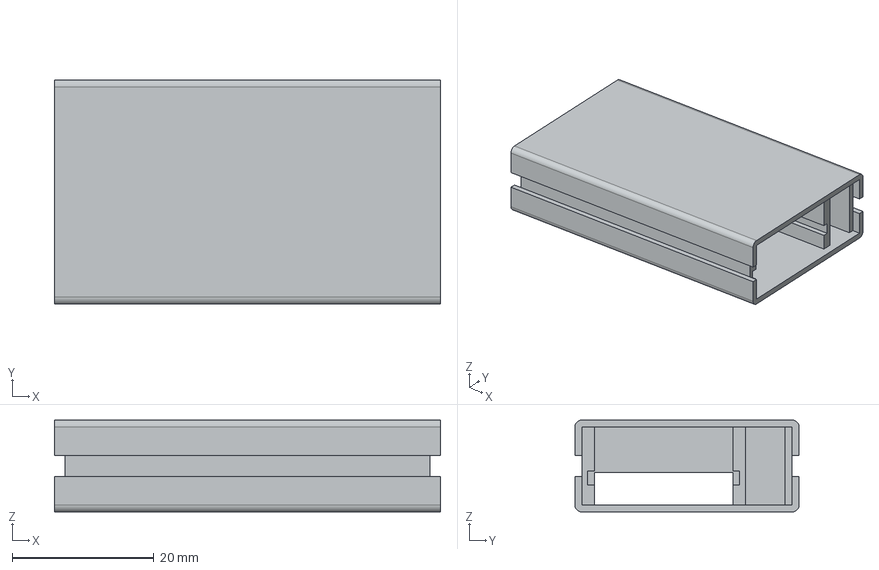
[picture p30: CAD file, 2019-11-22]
3D Model/DESIGN 2/Case.stp
54.6 x 31.7 x 13.0 mm

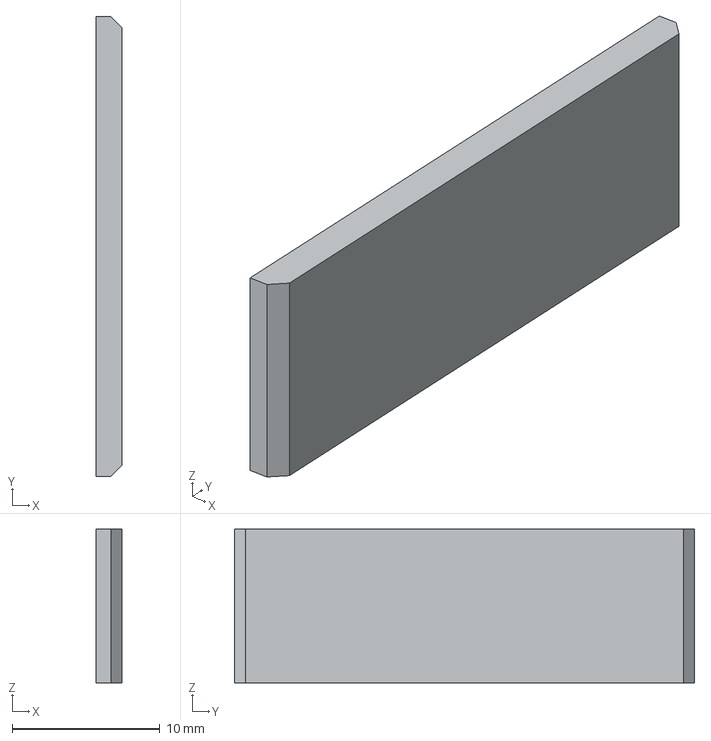
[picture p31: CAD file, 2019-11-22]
3D Model/EMAIL/Cap2.stp
1.75 x 31.1 x 10.4 mm

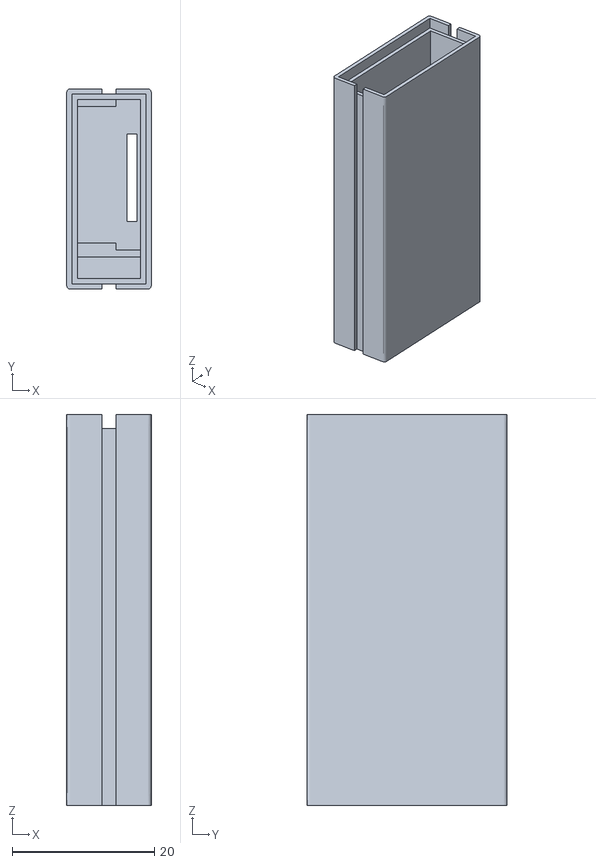
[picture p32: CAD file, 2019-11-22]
CASE.stl
11.9 x 28.2 x 55.0

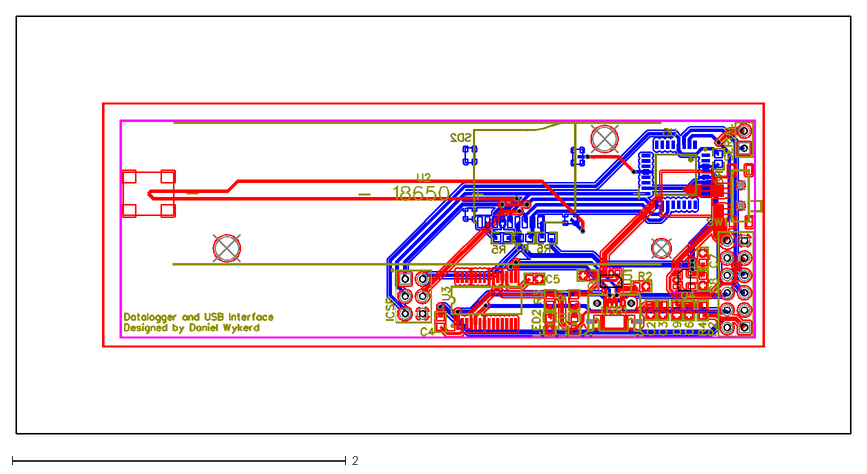
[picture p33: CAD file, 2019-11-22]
Nationals documents/Report File Nationals/PCB 1.dxf
5.00 x 2.50

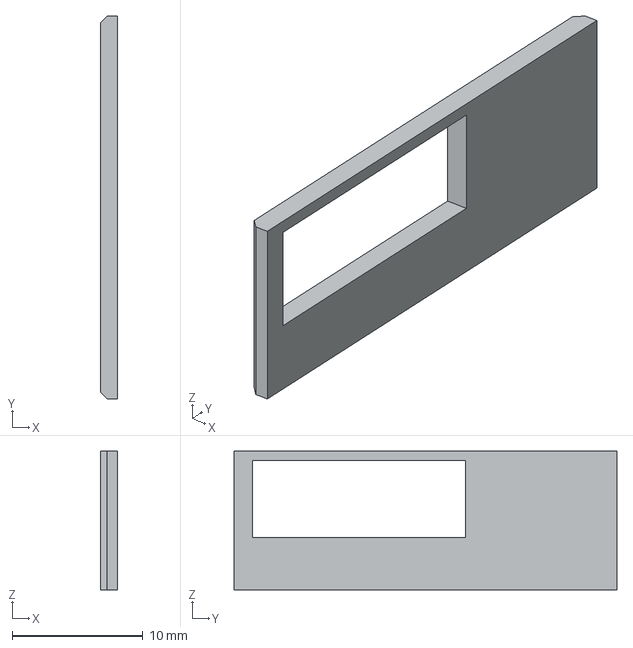
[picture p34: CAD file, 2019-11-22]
3D Model/DESIGN 2/CapHeader.stp
1.30 x 29.3 x 10.6 mm

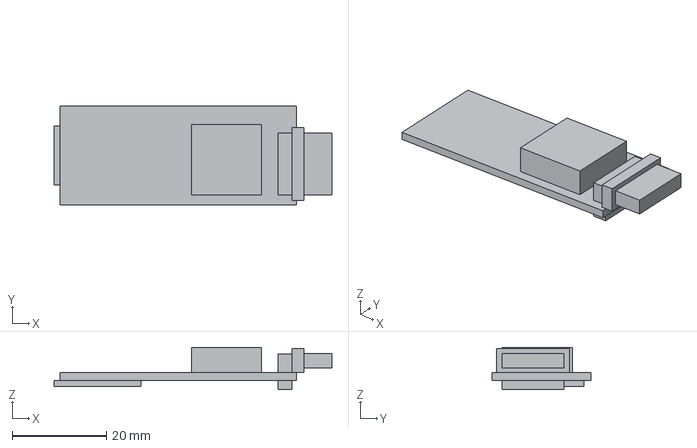
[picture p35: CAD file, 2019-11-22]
3D Model/EMAIL/PCB.stp
59.0 x 21.1 x 9.00 mm

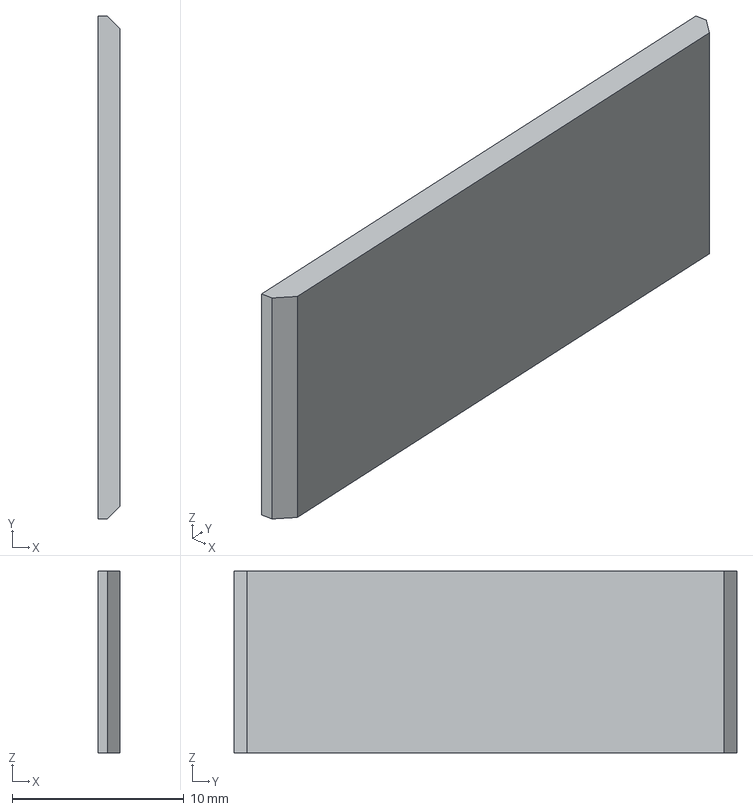
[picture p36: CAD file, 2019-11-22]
3D Model/DESIGN 2/CapSIM.stp
1.30 x 29.3 x 10.6 mm

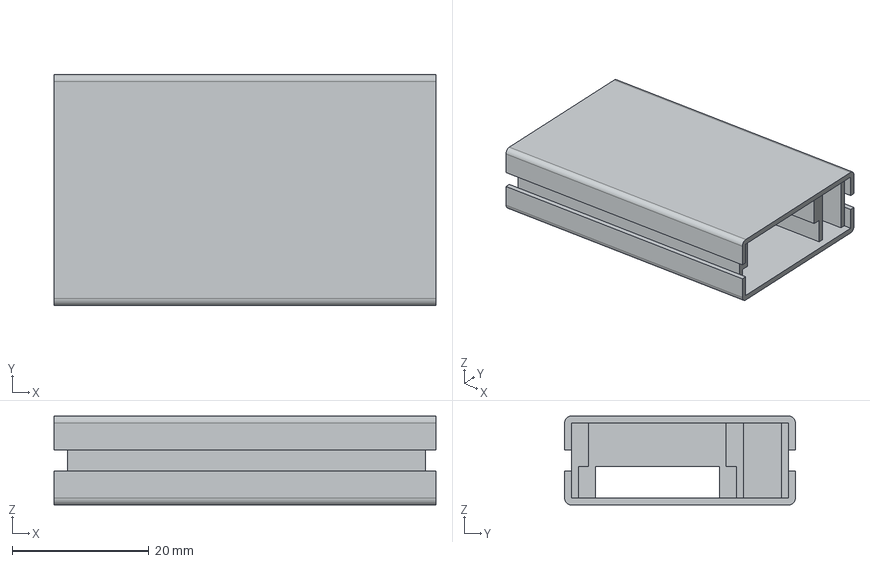
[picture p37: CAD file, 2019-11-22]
3D Model/EMAIL/CASE.stp
55.8 x 33.7 x 13.0 mm

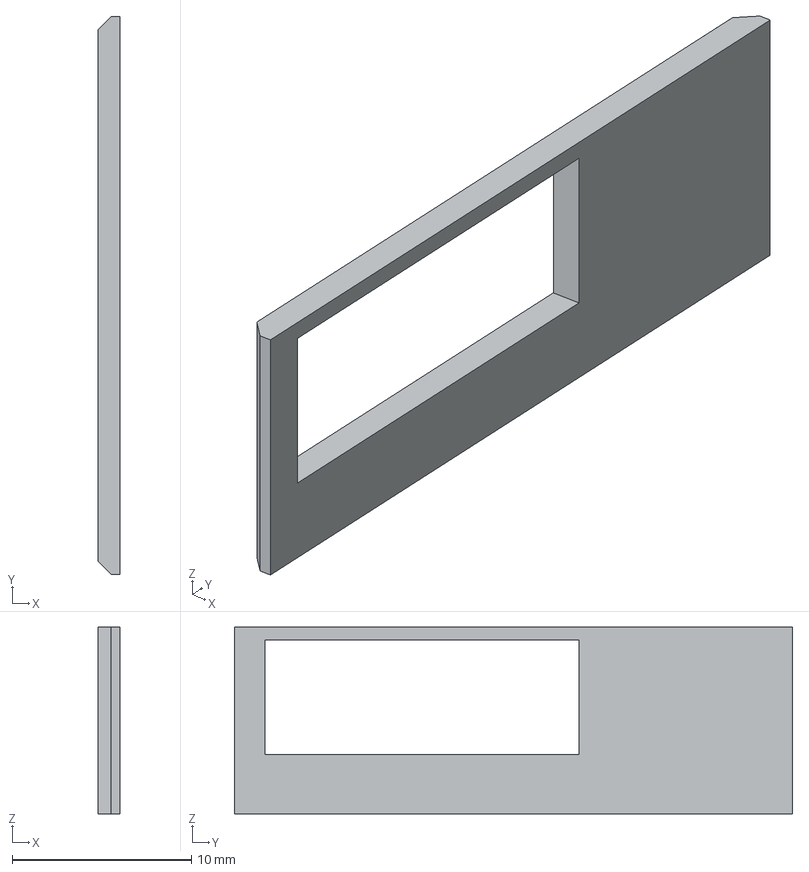
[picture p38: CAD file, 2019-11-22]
3D Model/EMAIL/Cap1.stp
1.25 x 31.1 x 10.4 mm

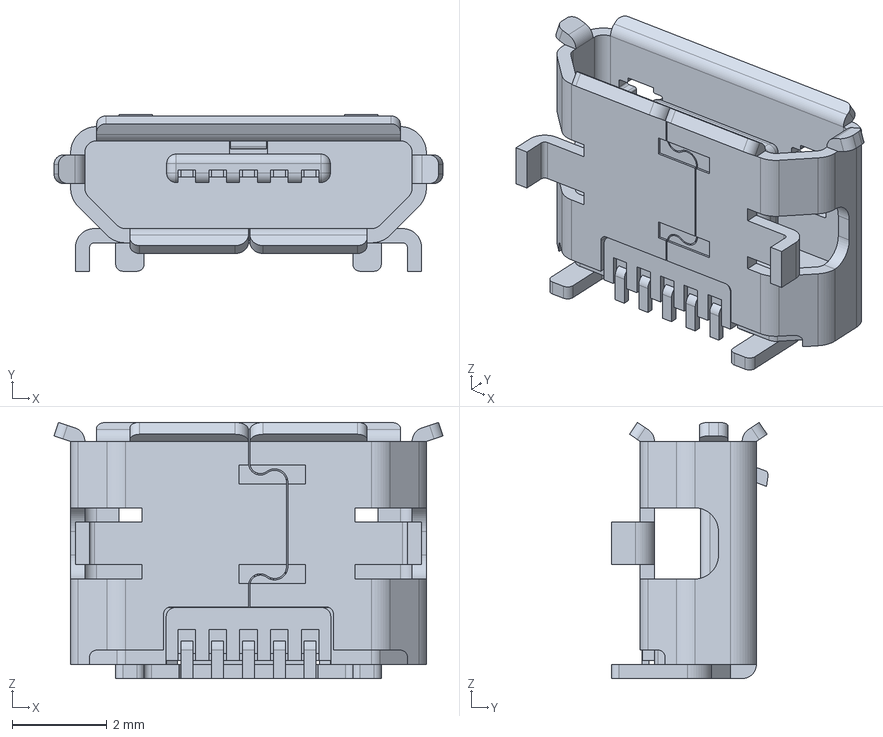
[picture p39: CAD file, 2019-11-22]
Nationals documents/Report File Nationals/Datalogger case/1050170001.stp
8.20 x 3.30 x 5.40 mm

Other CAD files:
Nationals documents/Report File Nationals/PCB 1.dxf Drawing 1.dwg
3D Model/DESIGN 2/PCB.stp
CASE_.stl

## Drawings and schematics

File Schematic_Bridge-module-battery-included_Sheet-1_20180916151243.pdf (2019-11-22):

# VCC Battery connector

# Charge circuit

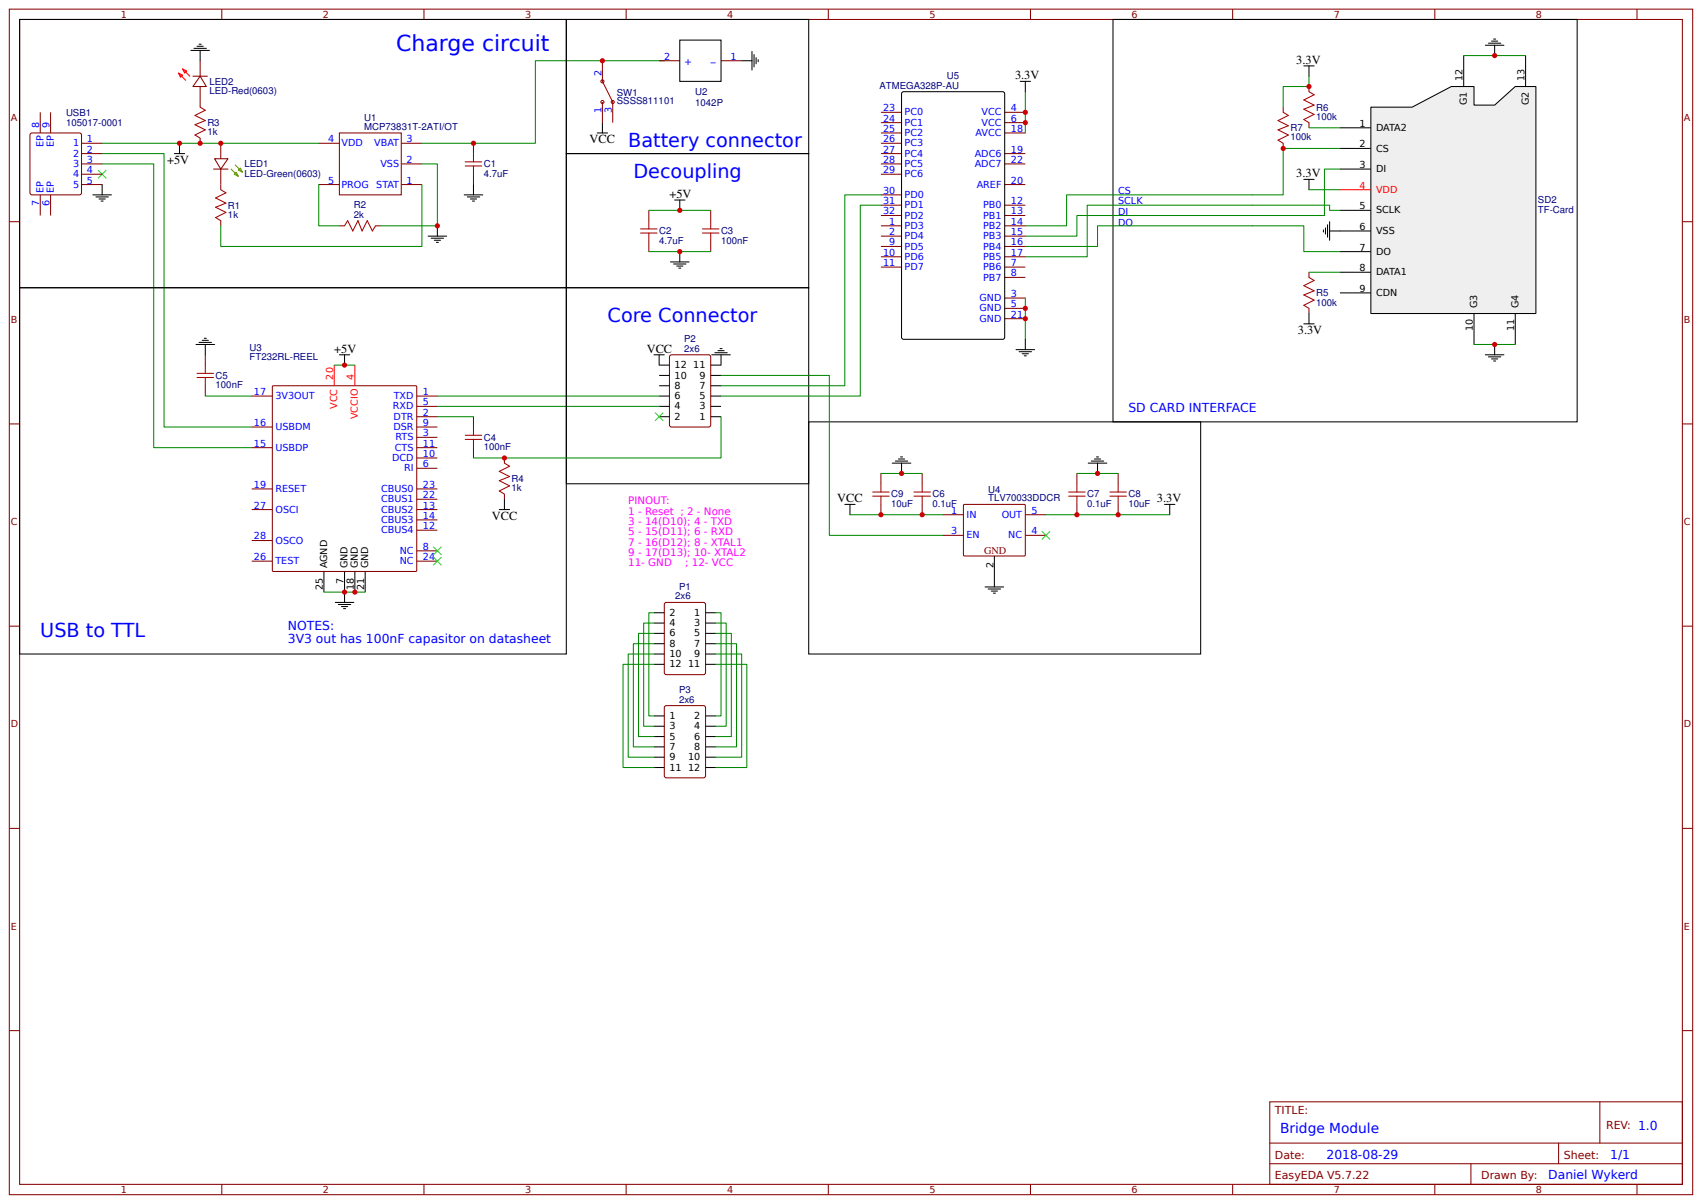
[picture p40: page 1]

NOTES:
3V3 out has 100nF capasitor on datasheet

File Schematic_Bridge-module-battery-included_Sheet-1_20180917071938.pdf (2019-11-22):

# VCC Battery connector

# Charge circuit

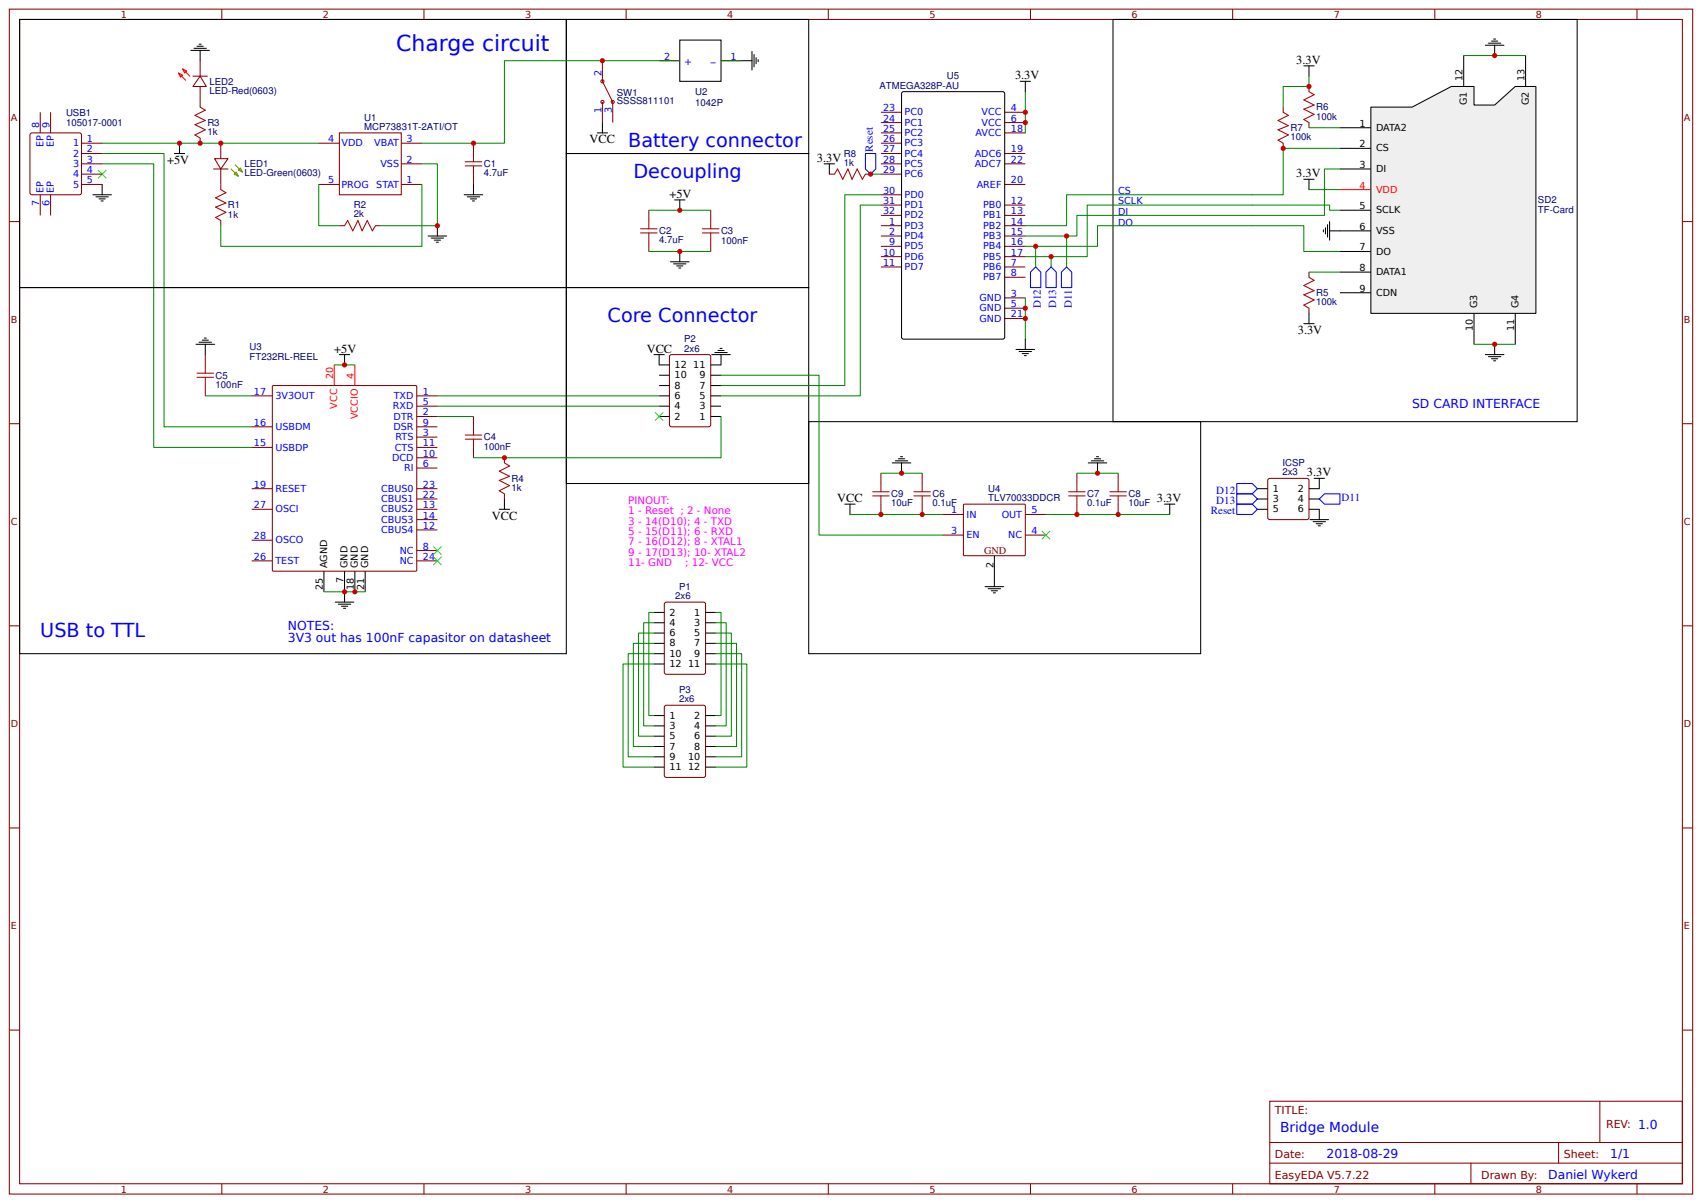
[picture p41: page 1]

NOTES:
3V3 out has 100nF capasitor on datasheet

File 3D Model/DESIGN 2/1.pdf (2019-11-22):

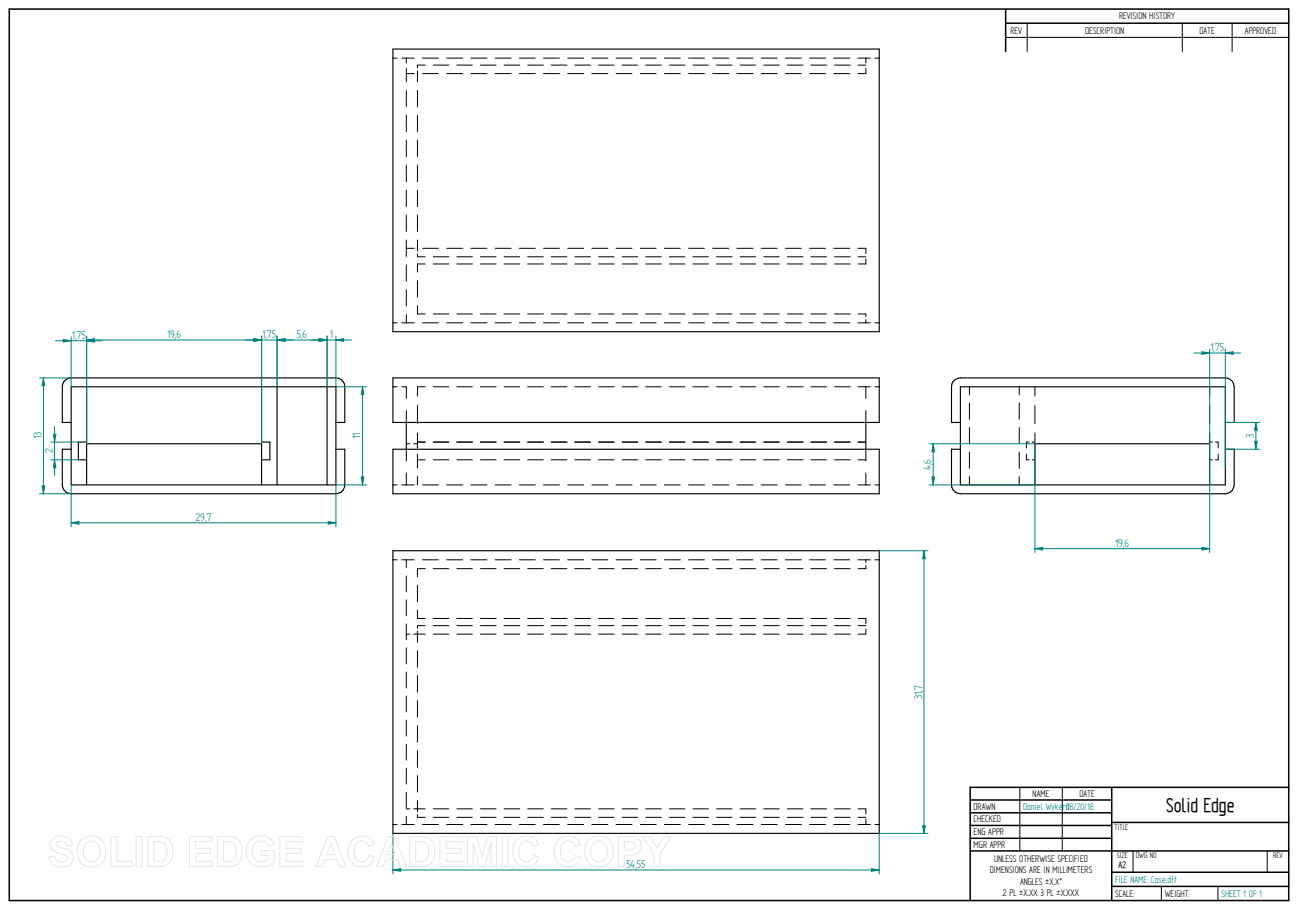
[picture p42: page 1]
SCALE:; WEIGHT:; SHEET 1 OF 1; REVISION HISTORY; REV; DESCRIPTION; DATE; APPROVED 13 2

DRAWN | Daniel Wykerd | 08/20/18
CHECKED
ENG APPR | | | TITLE
MGR APPR
UNLESS OTHERWISE SPECIFIED DIMENSIONS ARE IN MILLIMETERS ANGLES ±X.X° 2 PL ±X.XX 3 PL ±X.XXX | SIZE A2 | DWG NO | REV

NAME | DATE | Solid Edge

FILE NAME: Case.dft

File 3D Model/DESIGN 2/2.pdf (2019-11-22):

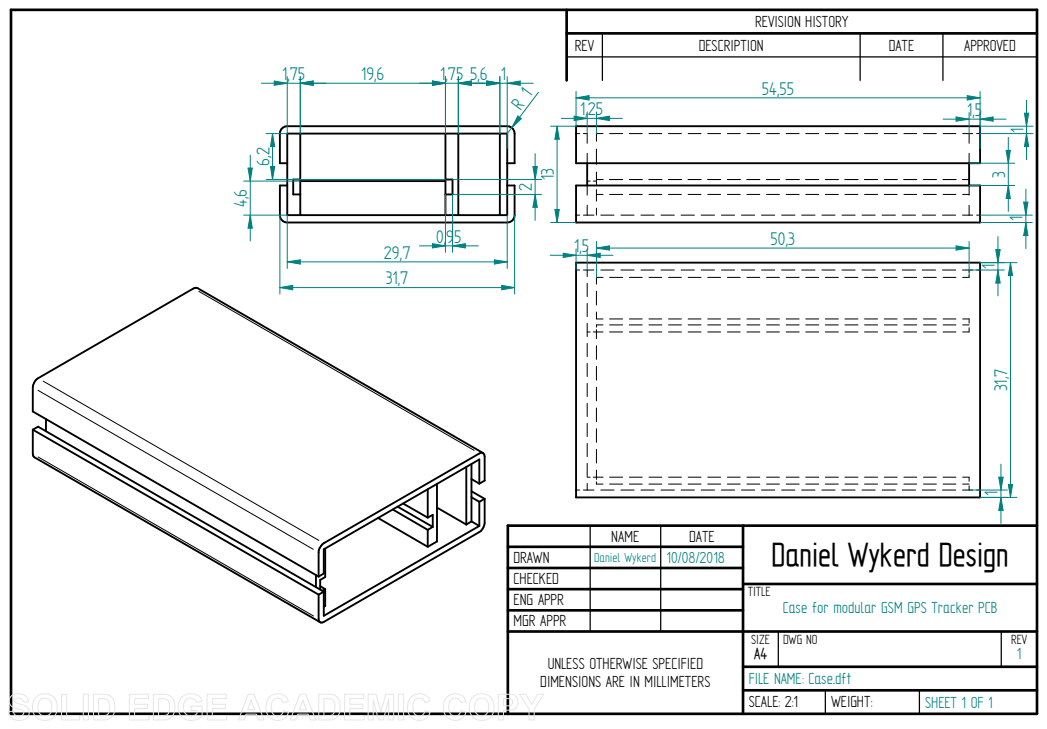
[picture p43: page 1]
SCALE: 2:1; WEIGHT:; SHEET 1 OF 1; REVISION HISTORY; REV; DESCRIPTION; DATE; APPROVED3¹,7

NAME | DATE | Daniel Wykerd Design

DRAWN | Daniel Wykerd | 10/08/2018
CHECKED
ENG APPR
MGR APPR
UNLESS OTHERWISE SPECIFIED DIMENSIONS ARE IN MILLIMETERS | SIZE A4 | DWG NO | REV 1

TITLE
Case for modular GSM GPS Tracker PCB

FILE NAME: Case.dft

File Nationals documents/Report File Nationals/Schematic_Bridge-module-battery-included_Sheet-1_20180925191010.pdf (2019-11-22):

# VCC Battery connector

# Charge circuit

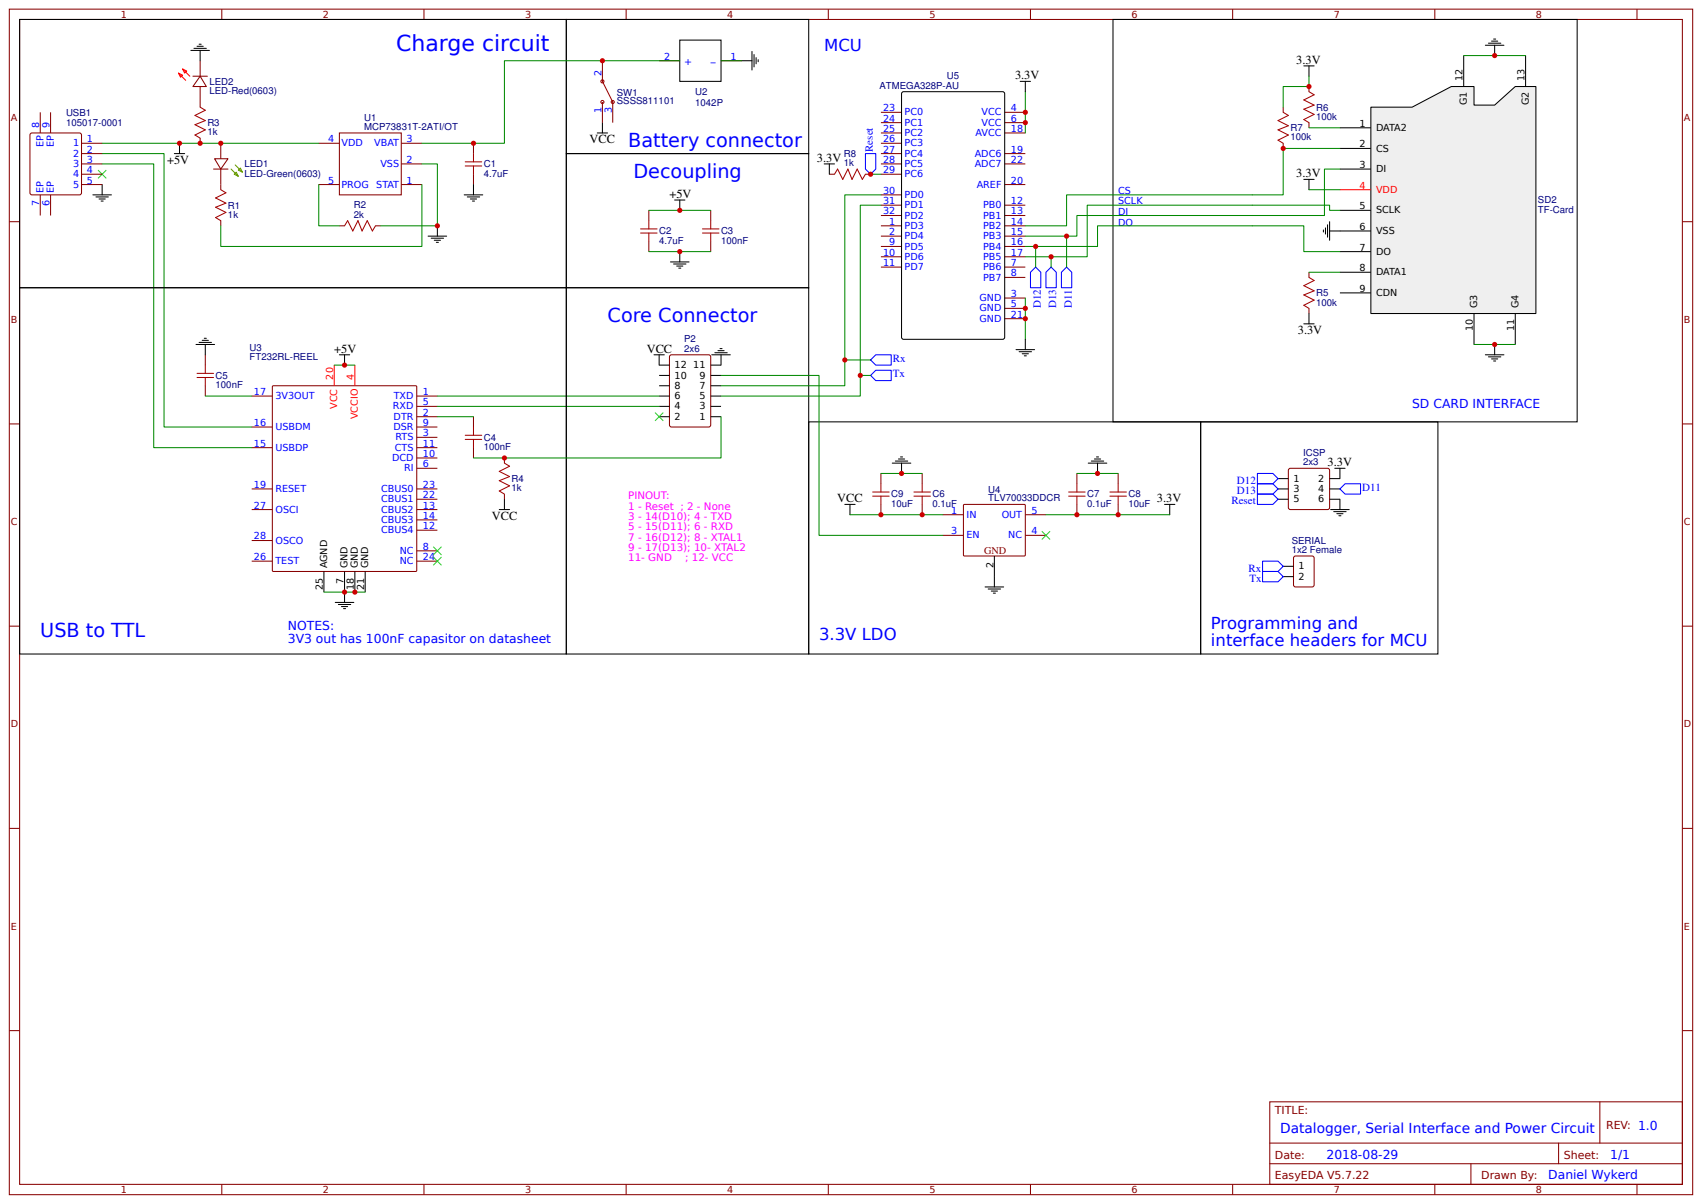
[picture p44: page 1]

NOTES:
3V3 out has 100nF capasitor on datasheet

Programming and
interface headers for MCU

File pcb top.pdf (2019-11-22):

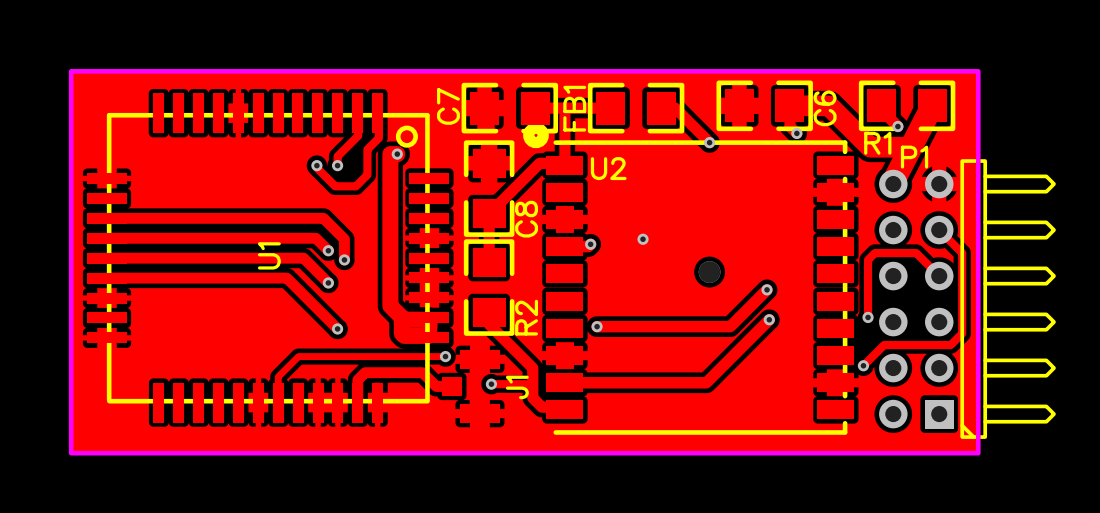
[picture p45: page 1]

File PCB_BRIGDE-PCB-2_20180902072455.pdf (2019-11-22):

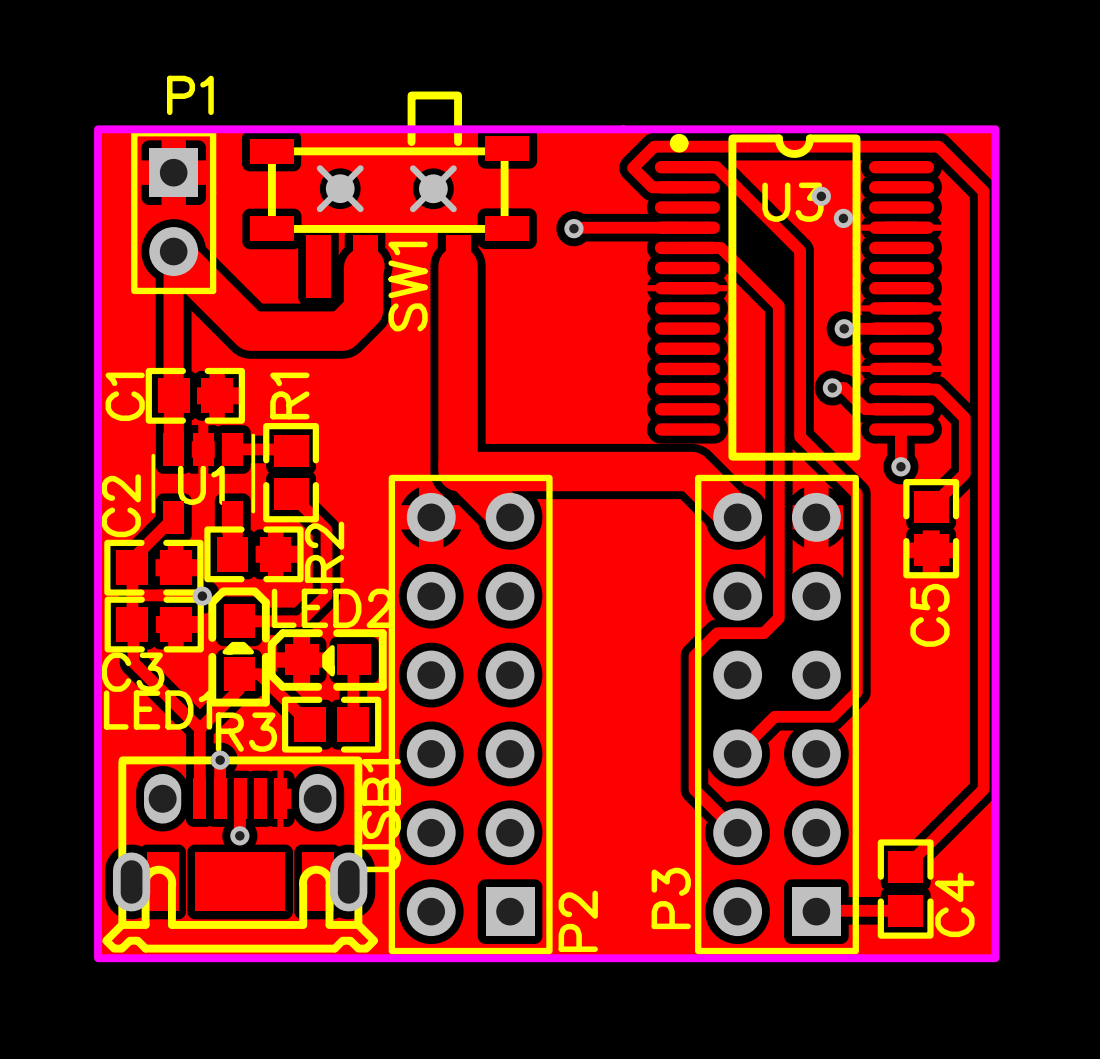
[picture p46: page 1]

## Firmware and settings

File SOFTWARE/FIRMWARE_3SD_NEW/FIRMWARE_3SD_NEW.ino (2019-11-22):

/*  Modular GSM GPS Tracker Firmaware 3A
 *  Software by Daniel Wykerd
 *  
 *  Features:
 *  - Auto SMS receive and loading into character arrays
 *  - Responds to the commands #HELP and #LOCATION
 *  
 *  This software is made to be used with REV 1.0 of the core module
 */

#include <String.h>
#include <SoftwareSerial.h>
#include <TinyGPS++.h>
#include <AltSoftSerial.h>
SoftwareSerial sms = SoftwareSerial(2, 3);
SoftwareSerial sd = SoftwareSerial(11, 12);
AltSoftSerial ssgps;

TinyGPSPlus gps;

char atResponse[120];
char notificationBuf[80];
char senderNum[20];
char msg[20];
boolean smsFound = false;
bool record = true;

const char format = ".GPX";

void setup() {
  // put your setup code here, to run once:
  sd.begin(9600);
  sms.begin(9600);
  ssgps.begin(9600);
  Serial.begin(115200);
  while(!networkStatus()); //Do nothing while there is no network
  sendAT("AT+CMGF=1");
  sendAT("AT+CNMI=2,1");
  deleteSMS();
  pinMode(13, OUTPUT);
  digitalWrite(13, LOW); 
  Serial.println(F("Boot Successful"));
  record = false;
  while (sms.available() > 0) sms.read(); //Clear the buffer before starting to prevent data loss in first sms
}

void deleteSMS(){
  sendAT("AT+CMGD=1,4");
}

void startSMS(){
  sms.print("AT+CMGS=\"" + String(senderNum) + "\"\r");
  delay(100);
}

void sendSMS(){
  sms.write(0x1A);
  sms.write(0x0D);
  sms.write(0x0A); 
  Serial.print(F("\nSMS Sent!"));
}

uint8_t preSec;

void loop() {
  preSec = gps.time.second();
  parseGPS();
  // put your main code here, to run repeatedly:
  checkForSMS();
  if (smsFound) {
    smsFound = false;
    Serial.print(F("From: "));
    Serial.print(senderNum);
    Serial.print(F("\nMessage: "));
    Serial.print(msg);
    String sMsg = String(msg);
    sMsg.toUpperCase();
    if (msg[0] == '#') {
      if (sMsg.indexOf('HELP') > 0) {
        startSMS();
        sms.print(F("HELP\n"));
        sms.print(F("Dev Build 3SD"));
        sms.print(F("\n  #LOCATION - Sends current location"
                    "\n  #RECORD - Logs location to SD Module"));
        sendSMS();  
      }else if (sMsg.indexOf('LOCATION') > 0) {
        startSMS();
        if (gps.satellites.value() >= 3) {
          //Sends location
          sms.print(F("Location: "));
          sms.print(gps.location.lat(), 6);
          sms.print(F(", "));
          sms.print(gps.location.lng(), 6);
          //Sends link to Google Maps
          sms.print(F("\nGoogle maps: "));
          sms.print(F("google.com/maps/place/"));
          sms.print(gps.location.lat(), 6);
          sms.print(F(","));
          sms.print(gps.location.lng(), 6);
          //Send amount of satellites for debugging
          sms.print(F("\nSatellites: "));
          sms.print(gps.satellites.value());
        } else {
          sms.print(F("Acquiring satellites, try later"));
        }
        sendSMS();
      }else if (sMsg.indexOf('RECORD') > 0) {
        recordCommand();
      }
    }
  }
  
  char ftime[20];
  sprintf(ftime, "%04d-%02d-%02dT%02d:%02d:%02dZ", gps.date.year(), gps.date.month(), gps.date.day(), gps.time.hour(), gps.time.minute(), gps.time.second());  
  
  if (((record)&&(preSec != gps.time.second()))&&(gps.satellites.value() >= 3)) {
    //Add to log
    sd.print("<trkpt lat=\"");
    sd.print(gps.location.lat(), 6);
    sd.print("\" lon=\"");  
    sd.print(gps.location.lng(), 6);
    sd.print("\">\n\r<time>");
    delay(100);
    sd.print(ftime);
    sd.print("</time>\n\r<ele>");
    sd.print(gps.altitude.meters());
    delay(100);
    sd.println("</ele></trkpt>");
    delay(100); 
  }
}

void recordCommand(){
  record = !record;
  startSMS();
  if (record){
    startGPX();
    sms.print(F("Started Recording"));
  }
  else{
    endGPX();
    sms.print(F("Ended Recording"));
  }
  sendSMS();
}

void startGPX(){
  digitalWrite(13, HIGH);
  delay(5000);
  while (gps.satellites.value() < 3) parseGPS();
  sd.print(gps.date.value());
  sd.print(gps.time.hour());
  sd.print(".GPX");
  delay(200);
  sd.println("<?xml version=\"1.0\" encoding=\"UTF-8\"?>");
  delay(50);
  sd.print("<gpx version=\"1.1\" xmlns=\"http://www.topograf");
  delay(50);
  sd.print("ix.com/GPX/1/1\" xmlns:xsi=\"http://www.w3.org/2001/XMLSchema-in");
  delay(50);
  sd.print("stance\" xsi:schemaLocation=\"http://www.topografix.com/GPX/1/1");
  delay(50);
  sd.println(" http://www.topografix.com/GPX/1/1/gpx.xsd\">");
  delay(50);
  sd.println("<trk><trkseg>");
  delay(100);
}

void endGPX() {
  sd.print("</trkseg>\n\r</trk>\n\r</gpx>");
  delay(1000);
  digitalWrite(13, LOW);
}

void parseGPS(){
  while (ssgps.available() > 0) gps.encode(ssgps.read());
}

void getSMSDat(){
  sendAT("AT+CMGR=1");
  if ((strstr(atResponse, "+CMGR:")) != NULL){ //Make sure the response is correct
    sscanf(atResponse, "%[^,],\"%[^\"]\"%[^\r\n]\r\n%[^\r\n]", NULL, senderNum, NULL, msg); //PARSE THE DATA
    deleteSMS(); //CLEAR THE MODEM MEMORY!
  }
}

void checkForSMS(){
  uint8_t i = 0;
  memset(notificationBuf, '\0', 100);
  while ((sms.available() != 0) && (i < 255)){
    notificationBuf[i] = sms.read();
    Serial.print(notificationBuf[i]);
    i++; 
  }
  delay(100);
  if ((strstr(notificationBuf, "+CMTI")) != NULL){
    getSMSDat();
    smsFound = true;
  }
}

boolean networkStatus(){
  sendAT("AT+CGREG?");

  //parse the response
  if ((strstr(atResponse, "+CGREG:")) != NULL){ //Make sure the response is correct
    strtok(atResponse," :,");
    strtok (NULL," :,");  
    if ((strstr ((strtok (NULL," :,")),"1")) != NULL) return true; 
    else return false;
    
  } else return false; 
}

void sendAT(char* atCommand){
  uint8_t i=0;
  memset(atResponse, '\0', 100); //Clear the char array
  while( sms.available() > 0) sms.read();
  sms.println(atCommand);     //Print the at command
  Serial.print(F("<- "));
  Serial.println(atCommand);
  delay(100);
  unsigned long initialTime = millis();
  do{
    if (sms.available() != 0){
      atResponse[i] = sms.read();
      i++; 
    }
  } while((strstr(atResponse, "OK") == NULL) && (millis() - initialTime)<2000); //Keep searching for response for 2 sec or until "OK" which indicates the end of a AT response
  Serial.print(F("-> "));Serial.println(atResponse);
}

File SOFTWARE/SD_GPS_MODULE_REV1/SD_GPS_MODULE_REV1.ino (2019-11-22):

/*
 * Software fo the Snap|Click|Track SD module rev 1
 * Software version 1; Created 7 September 2018
 * 
 * This code is made for one way data transfer to SD card
 * 
 * Usage instructions to interface with other modules:
 * - Once the module is turnt on it waits for a string of data on sent to SerialSoftware(3,2)
 * - This string is loaded into the filename buffer. All data sent after this point will be written to the filename path.
 * - The software only supports writng of data, no data can be retrieved. Thie source code can be modified to send back data though serial.
 * - Send 64 bytes or less at a time!
 */

#include <SPI.h>
#include <SD.h>
#include <SoftwareSerial.h>
SoftwareSerial ss = SoftwareSerial(3,2);

File dataFile;

int i = 0;

char filename[25];

void setup() {
  // put your setup code here, to run once:
  Serial.begin(9600);
  //ss.begin(9600);
  Serial.println(F("BOOTING"));
  if (!SD.begin()) {
    Serial.println(F("SD FAILED"));
    return;
  }
  Serial.println(F("DONE"));
  while (!Serial.available()); //Do nothing
  while (Serial.available()){  //Read data to filename
    filename[i] = Serial.read();  
    Serial.print(filename[i]);
    i++; 
    delay(10); //wait for more data
  }

  Serial.print("\n\rFilename: ");  
  Serial.println(filename);
  //Create the file
  dataFile = SD.open(String(filename), FILE_WRITE);
  dataFile.close();
}

void loop() {
  // put your main code here, to run repeatedly:
  dataFile = SD.open(String(filename), FILE_WRITE);
  while (Serial.available()){
    dataFile.print((char) Serial.read());
    Serial.print(".");
  }
  dataFile.close();
}
